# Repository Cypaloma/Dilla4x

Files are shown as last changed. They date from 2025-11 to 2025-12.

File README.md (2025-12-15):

# 🎛️ Dilla4x - Open Source Device Platform

**A minimalist, accessible 4x4 ortholinear input device inspired by classic MPC layouts.**

> *"Get ready for the up-and-coming, whatever it is." - J Dilla*

   

> 💭 **Stressed out? Overwhelmed?** Try the [Bio-Debugger](tools/bio-debugger/README.md) - a mental health resource for de-escalation during technical challenges.

---

## 🎵 What is Dilla4x?

The **Dilla4x** is a fully open-source hardware and software platform. Built around the **Arduino Pro Micro (ATmega32U4)**, it serves as both a serious creative tool and a learning platform for hardware development.

### ✨ Key Features

| Feature | Description |
| :--- | :--- |
| **🎹 16 Mechanical Keys** | Uses standard **Cherry MX-compatible** keyswitches for a responsive, premium feel. |
| **♿ Accessible Design** | Unique **"chord trigger" octave shifting** (MIDI firmware) or custom layouts via VIA allow full creative control for users with diverse needs. |
| **🔌 Plug-and-Play** | **USB HID/MIDI compatible**. Works instantly with DAWs, browsers, games, and creative software. No drivers needed. |
| **🛠️ Hackable Core** | Powered by **ATmega32U4**. Choose between MIDI or QMK firmware, or create your own. |
| **🔓 Open Hardware** | Simple PCB and 3D-printed enclosure designs that are easy to print, assemble, and modify. |

---

## 🚀 Quick Start

Everything you need to get started is in our comprehensive **[Wiki](wiki/Home.md)**.

1.  **🛠️ Build It**
    *   Follow the **[Step-by-Step Assembly Guide](wiki/hardware/Assembly-Guide.md)** to put your hardware together.
2.  **⚡ Flash Firmware**
    *   **Download from [GitHub Releases](https://github.com/Cypaloma/Dilla4x/releases/tag/v0.3.1)**:
        *   **MIDI Firmware** (v0.3.0): `dilla4x-midi-v0.3.0.hex` ✅ Stable
        *   **QMK Firmware** (v0.1.1-alpha): ⚠️ **ALPHA - UNTESTED ON HARDWARE**
            
            > **CAUTION**: This firmware has NOT been tested on physical hardware. All devices were sent to participants before testing. Use at your own risk and please report issues.
            
            1.  **Manual Reset Required**: Double-tap the physical reset button to enter bootloader mode. The auto-flash recovery script will **NOT** work for QMK.
            2.  Flash using QMK Toolbox or CLI:
                ```bash
                qmk flash dilla4x-qmk-v0.1.1-alpha.hex
                ```
3.  **🎧 Use It**
    *   **MIDI Mode**: Learn the layout in **[How to Use Dilla4x-MIDI](wiki/software/How-to-Use-Dilla4x-MIDI.md)**
    *   **QMK Mode**: Remap keys with VIA - see **[QMK README](firmware/qmk/dilla4x/readme.md)**
    *   **Web App**: Download `dilla4x-web-v0.1.0.zip` or use the **[Web Manual](wiki/software/Web-Dilla4x-Manual.md)**

---

## 🎹 Web Dilla4x Companion App

**No software to install.** The Dilla4x comes with a powerful browser-based companion app that turns your controller into a basic **Sampler and Synthesizer** instantly.

*   **Launch it**: Open [`tools/web-dilla4x/index.html`](tools/web-dilla4x/index.html) in Chrome/Edge
*   **Features**:
    *   **Sampler**: Drag & drop WAV/MP3s, per-pad pitch/envelope controls.
    *   **Synth**: Full subtractive synth engine with A/D envelope and low-pass filter.
    *   **Visualizer**: Real-time oscilloscope and VU meter.
*   **Manual**: [Read the Web Dilla4x Guide](wiki/software/Web-Dilla4x-Manual.md)

---

## 🧠 Firmware Options

The Dilla4x supports **two firmware modes** - choose based on your use case:

### 🎵 Dilla4x-MIDI Firmware (v0.3.0)

A stateless, low-latency MIDI engine designed for musical performance.

*   **💻 Source**: [`firmware/Dilla4x-MIDI/`](firmware/Dilla4x-MIDI/)
*   **✨ Features**:
    *   Chromatic MIDI notes (C2-D#3)
    *   Chord-based octave shifting (accessibility feature)
    *   Class-compliant USB MIDI
    *   Recovery mode for failed uploads
*   **📖 Guide**: [Firmware Documentation](wiki/development/Dilla4x_Firmware.md) | [Usage Manual](wiki/software/How-to-Use-Dilla4x-MIDI.md)
*   **🔧 Modify**: [Arduino IDE Guide](wiki/development/Arduino-Development.md) | [PlatformIO Guide](wiki/development/VSCodium-PlatformIO-MIDI-Guide.md)

### ⌨️ Dilla4x-QMK Firmware (v0.1.0)

A versatile QMK-based firmware for programmable macros, gaming, and accessibility.

*   **� Source**: [`firmware/qmk/dilla4x/`](firmware/qmk/dilla4x/)
*   **✨ Features**:
    *   VIA support for real-time remapping
    *   N-Key Rollover (NKRO)
    *   Mouse keys and media control
    *   MIDI mode support
    *   Community layout compatible (ortho_4x4)
*   **📖 Guide**: [QMK README](firmware/qmk/dilla4x/readme.md) | [VIA Setup](firmware/qmk/dilla4x/keymaps/via/VIA_SETUP.md)
*   **🔧 Modify**: Standard QMK development workflow

---

## 🔮 Roadmap

We are interested in expanding the Dilla4x ecosystem. Check [ROADMAP.md](ROADMAP.md) for full details.

Future directions:
- [ ] **Visual Arts**: Workflows for TouchDesigner, Resolume, and p5.js.
- [ ] **Ergonomics**: Low-profile enclosure designs.
- [ ] **Firmware Variants**: Additional community-contributed firmware options.

---

## 📂 Repository Structure

```text
├── 3d-prints/         # STL files for the enclosure
├── firmware/
│   ├── Dilla4x-MIDI/  # Arduino MIDI firmware (v0.3.0)
│   └── qmk/dilla4x/   # QMK programmable firmware (v0.1.0)
├── tools/
│   └── web-dilla4x/   # Browser-based sampler/synth app
├── wiki/              # Complete documentation (Build, Code, Play)
│   ├── development/   # Coding guides
│   ├── hardware/      # BOM & Assembly
│   ├── software/      # Usage manuals for both firmwares
│   └── sound/         # Music theory & creative guides
├── ROADMAP.md         # Future development plans
└── LICENSE            # Apache 2.0
```

---

## 🤝 Contributing

This project is open source under the **Apache 2.0 License**. Contributions to hardware, firmware, and documentation are welcome!

1.  Fork the repository
2.  Create your feature branch
3.  Submit a Pull Request

Whether you're interested in MIDI, QMK, hardware design, or creative applications - there's room for you to contribute!

---

*Dedicated to the legacy of James Dewitt Yancey.*

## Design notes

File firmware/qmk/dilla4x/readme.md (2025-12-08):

# Dilla4x

A 4x4 ortholinear MIDI controller and macro pad with VIA support.

* Keyboard Maintainer: [Dilla4x Community](https://github.com/Cypaloma/Dilla4x)
* Hardware Supported: ATmega32U4 (Arduino Pro Micro)
* Hardware Availability: [Build Guide](../../wiki/hardware/Assembly-Guide.md)

> **⚠️ TESTING STATUS**: This firmware (v0.1.0) follows 2025 QMK standards (data-driven config). It should compile correctly but has not been tested on hardware yet.

> **⚡ FIRMWARE SIZE**: ATmega32U4 has limited flash (28KB). VIA + MIDI + NKRO uses ~26KB. If you encounter size errors, disable NKRO or mousekeys in VIA keymap.

## Features

- **Dual Purpose**: MIDI controller + programmable macro pad
- **VIA Support**: Real-time remapping (requires external VIA definition - see below)
- **Gaming Ready**: N-Key Rollover, mouse keys, media control
- **MIDI Notes**: Chromatic C2-D#3 (matches Dilla4x-MIDI firmware)

## Make Commands

Compile default keymap:

    make dilla4x:default

Compile VIA keymap:

    make dilla4x:via

Flash to device (enter bootloader first):

    make dilla4x:via:flash

## Bootloader

Enter the bootloader in 3 ways:

* **Bootmagic reset**: Hold top-left key while plugging in
* **Physical reset**: Bridge RST to GND on Pro Micro twice quickly  
* **Keycode in layout**: Not implemented by default

## Default Keymap

Layer 0 - MIDI Notes (Chromatic C2 to D#3):

```
┌─────┬─────┬─────┬─────┐
│ C3  │ C#3 │ D3  │ D#3 │  MIDI 48-51
├─────┼─────┼─────┼─────┤
│ G#2 │ A2  │ A#2 │ B2  │  MIDI 44-47
├─────┼─────┼─────┼─────┤
│ E2  │ F2  │ F#2 │ G2  │  MIDI 40-43
├─────┼─────┼─────┼─────┤
│ C2  │ C#2 │ D2  │ D#2 │  MIDI 36-39
└─────┴─────┴─────┴─────┘
```

## VIA Support

**IMPORTANT**: VIA configuration is NOT stored in QMK firmware. You must:

1. Flash the `via` keymap to your device
2. Submit keyboard definition to [the-via/keyboards](https://github.com/the-via/keyboards)
3. Wait for PR approval

See [VIA_SETUP.md](keymaps/via/VIA_SETUP.md) for detailed instructions.

**Quick test** (before PR approval):
- Visit https://usevia.app/
- Go to "Design" tab
- Upload JSON from VIA_SETUP.md
- Test your layout

## Building from Source

### Prerequisites

Install QMK:

```bash
# macOS
brew install qmk/qmk/qmk

# Linux
python3 -m pip install --user qmk

# Windows - install QMK Toolbox
```

Setup QMK:

```bash
qmk setup
```

### Clone & Link

```bash
# Clone Dilla4x repo
git clone https://github.com/Cypaloma/Dilla4x.git
cd Dilla4x

# Link to QMK keyboards directory
ln -s "$(pwd)/firmware/qmk/dilla4x" ~/qmk_firmware/keyboards/dilla4x
```

### Compile

```bash
qmk compile -kb dilla4x -km via
```

### Flash

```bash
# Put device in bootloader mode, then:
qmk flash -kb dilla4x -km via
```

## Firmware Details

- **MCU**: ATmega32U4
- **Bootloader**: Caterina
- **Layout**: 4x4 ortholinear (16 keys direct pin)
- **MIDI**: Basic mode (Note On/Off, fixed velocity)
- **Debounce**: 30ms (matches Arduino firmware)

## Resources

* [QMK Documentation](https://docs.qmk.fm/)
* [VIA Configurator](https://usevia.app/)
* [Build Guide](../../wiki/hardware/Assembly-Guide.md)
* [Arduino Firmware](../Dilla4x-MIDI/)

## License

Apache 2.0 (same as parent project)

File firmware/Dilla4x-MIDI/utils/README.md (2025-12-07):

# Dilla4x Diagnostic Utilities

Central hub for hardware diagnostics and firmware testing tools.

## Quick Decision Tree

**What are you doing?**

1. **Just finished soldering Arduino to headers (bottom section only)**
   - Use: [`crosstalk_detector`](#crosstalk_detector)
   - Purpose: Check for solder bridges between pins

2. **Assembled full unit (buttons attached to Arduino)**
   - Use: [`connection_scout`](#connection_scout)
   - Purpose: Verify button connections and pin mapping

3. **Device won't flash / USB not responding**
   - Use: [`recovery`](#recovery)
   - Purpose: Unbrick device with minimal firmware

4. **Debugging firmware logic (debounce, MIDI, etc.)**
   - Use: [`testing/firmware_test`](#firmware-test)
   - Purpose: Test firmware with configurable modes

---

## Production Testing Workflow

```
┌─────────────────────────────────────────┐
│ 1. Bottom Section QA                    │
│    ├─ Solder Arduino Pro Micro to headers│
│    └─ Run: crosstalk_detector           │
│       ✓ Clean = No shorts detected      │
│       ✗ Issue = Fix solder bridges      │
└─────────────────────────────────────────┘
                   ↓
┌─────────────────────────────────────────┐
│ 2. Full Assembly QA                     │
│    ├─ Attach top button section          │
│    └─ Run: connection_scout              │
│       ✓ Clean = All buttons respond     │
│       ✗ Issue = Check button wiring     │
└─────────────────────────────────────────┘
                   ↓
┌─────────────────────────────────────────┐
│ 3. Functional Test                      │
│    └─ Flash main firmware                │
│       ✓ Pass = Device ready for use     │
│       ✗ Bricked = Use recovery tool     │
└─────────────────────────────────────────┘
```

---

## Utility Reference

### `crosstalk_detector`
**Tests**: Bottom section (Arduino + headers)  
**Detects**: Solder bridges between pins

**When to use**:
- After soldering Arduino Pro Micro
- Before attaching buttons
- When ghost presses occur (multiple keys at once)

**Expected output**:
- ✅ **Clean**: `Status: Clean (No Crosstalk Detected)`
- ❌ **Issue**: `SHORT DETECTED: Pin X <---> Pin Y`

**Location**: [`utils/crosstalk_detector/`](file:///home/morp/Documents/coding/projects/Dilla4x/firmware/Dilla4x-MIDI/utils/crosstalk_detector/)

---

### `connection_scout`
**Tests**: Top section (button connections)  
**Detects**: Button-to-pin mappings and connection integrity

**When to use**:
- After full assembly
- When a button doesn't respond
- To verify Config.h pin mapping

**Expected output**:
- ✅ **Clean**: Only shows activity when buttons pressed
- ❌ **Issue**: Pins stuck LOW or no response

**Location**: [`utils/connection_scout/`](file:///home/morp/Documents/coding/projects/Dilla4x/firmware/Dilla4x-MIDI/utils/connection_scout/)

---

### `recovery`
**Purpose**: Unbrick device when main firmware crashes  
**Includes**: Auto-flash script for automated recovery

**When to use**:
- Device won't show up in Arduino IDE
- USB enumeration fails
- Main firmware locks up device

**How to use**:
1. Flash `recovery.ino` to device
2. If upload fails, run `./auto_flash.sh`
3. Device will blink TX LED (confirmed recovery mode)
4. Flash desired firmware

> [!NOTE]
> **Recovery vs Firmware Recovery Mode**  
> - **This tool** (`recovery/`): Separate minimal sketch for unbricking
> - **Firmware recovery mode**: Hold Keys 0+15 at boot (built into main firmware)

> [!IMPORTANT]
> **Sometimes recovery firmware must be flashed first** if the current firmware utilizes the USB interface, preventing normal uploads.

**Location**: [`utils/recovery/`](file:///home/morp/Documents/coding/projects/Dilla4x/firmware/Dilla4x-MIDI/utils/recovery/)

---

### `firmware_test`
**Purpose**: Configurable test harness for debugging firmware  
**Located in**: [`testing/firmware_test/`](file:///home/morp/Documents/coding/projects/Dilla4x/firmware/Dilla4x-MIDI/testing/firmware_test/)

**Test modes** (configure in source):
- `TEST_WATCHDOG`: Enable/disable watchdog timer
- `TEST_MIDIUSB`: Enable/disable MIDIUSB library (tests pin conflicts)
- `TEST_VERBOSE`: Detailed trace logging

**When to use**:
- Debugging debounce logic
- Testing if MIDIUSB causes issues
- Validating firmware changes

**See**: [`testing/README.md`](file:///home/morp/Documents/coding/projects/Dilla4x/firmware/Dilla4x-MIDI/testing/README.md) for full testing documentation

---

## Manual Reset Button Access

> [!WARNING]
> **Current limitation**: Reset button requires disassembly to access (must jump reset pin to ground with screwdriver).
> 
> **Future improvement** (see [ROADMAP.md](file:///home/morp/Documents/coding/projects/Dilla4x/ROADMAP.md)):  
> Add small hole in bottom plate for tac switch, allowing reset access with assembly screwdriver.

---

## Troubleshooting

### "Device not detected by Arduino IDE"
1. Check USB cable (must be data cable, not charge-only)
2. Try [`recovery`](#recovery) tool with auto-flash script
3. Manually jump reset to ground twice quickly (bootloader mode)

### "Multiple buttons trigger at once"
- Run [`crosstalk_detector`](#crosstalk_detector) on bottom section
- Look for solder bridges between pins

### "One button doesn't work"
- Run [`connection_scout`](#connection_scout)
- Check if pin shows activity when button pressed
- Verify pin matches Config.h mapping

### "Firmware behaves strangely"
- Use [`firmware_test`](#firmware-test) to isolate issue
- Test with MIDIUSB disabled, watchdog disabled, etc.

---

## Contributing

When adding new utilities:
1. Create subdirectory in `utils/`
2. Add standardized header comment (see existing utilities)
3. Create `README.md` in utility directory
4. Update this central README with decision tree entry

**See**: [ROADMAP.md](file:///home/morp/Documents/coding/projects/Dilla4x/ROADMAP.md) for planned improvements

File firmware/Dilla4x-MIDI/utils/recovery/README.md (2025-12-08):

# Recovery Tool

Minimal firmware for unbricking soft-locked devices.

## Purpose

Provides a **safe idle state** when main firmware crashes or prevents USB upload.

## When to Use

- ❌ Device won't show up in Arduino IDE
- ❌ USB enumeration fails  
- ❌ Main firmware locks up device
- ❌ Normal upload fails with timeout errors

> [!IMPORTANT]
> **Two Different Recovery Mechanisms**:
> 
> 1. **This tool** (`recovery/`): Separate minimal sketch for complete unbrick
> 2. **Firmware recovery mode**: Built into main firmware (hold Keys 0+15 at boot)
> 
> Use **this tool** if firmware recovery mode doesn't work or main firmware won't let you upload.

> [!NOTE]
> **Sometimes recovery firmware must be flashed first** if current firmware utilizes USB interface, preventing normal uploads.

## Tools Included

- **`recovery.ino`**: Minimal blink sketch (TX LED only)
- **`auto_flash.sh`**: Linux automated upload script
- **`auto_flash.bat`**: Windows automated upload script
- **`auto_flash_mac.command`**: macOS automated upload script (double-clickable in Finder)

## Usage

### Linux
```bash
cd firmware/Dilla4x-MIDI/utils/recovery/
./auto_flash.sh
```

### Windows
1. Open Command Prompt or PowerShell
2. Navigate to `firmware\Dilla4x-MIDI\utils\recovery\`
3. Run `auto_flash.bat`
```cmd
cd firmware\Dilla4x-MIDI\utils\recovery
auto_flash.bat
```

### macOS
**Option A (Finder)**: Double-click `auto_flash_mac.command`  
**Option B (Terminal)**:
```bash
cd firmware/Dilla4x-MIDI/utils/recovery/
./auto_flash_mac.command
```

> [!NOTE]
> All scripts require `arduino-cli` to be installed and in your PATH.
> Install from https://arduino.github.io/arduino-cli/

### Method 1: Manual Upload

```bash
cd firmware/Dilla4x-MIDI/utils/recovery/

# Try normal upload first
arduino-cli upload -p /dev/ttyACM0 --fqbn arduino:avr:micro ./

# If that fails, manually jump reset to ground twice (bootloader mode)
# Then immediately upload
arduino-cli upload -p /dev/ttyACM0 --fqbn arduino:avr:micro ./
```

### Method 2: Automated (Recommended)
```bash
cd firmware/Dilla4x-MIDI/utils/recovery/

# Run auto-flash script (watches for ports, handles bootloader)
./auto_flash.sh

# Optional: Specify specific port
PORT_HINT=/dev/ttyACM0 ./auto_flash.sh
```

## What It Does

1. Compiles `recovery.ino` to hex
2. Watches for USB serial ports
3. Attempts upload with retries
4. Periodically triggers bootloader with 1200bps touch
5. Continues until upload succeeds

## Expected Behavior

### After Successful Upload
- **TX LED blinks** rapidly (150ms on/off)
- **RX LED stays off**
- Device appears as `/dev/ttyACM*` in Arduino IDE
- Normal firmware can now be uploaded

### If Still Failing
1. Check USB cable (must be data cable, not charge-only)
2. Try different USB port on computer
3. Verify Arduino Pro Micro isn't damaged (check for shorts/burns)
4. Try manual bootloader trigger (double-tap reset)

## Auto-Flash Script Details

**Environment variables**:
- `FQBN`: Board type (default: `arduino:avr:micro`)
- `PORT_HINT`: Specific port to target (optional)
- `BUILD_DIR`: Custom build directory (optional)

**How it works**:
- Continuously scans for ports
- Attempts rapid uploads when port detected
- Sends 1200bps reset signal to trigger bootloader
- Retries until successful

## Troubleshooting

### "No ports found"
- Device not connected or completely bricked  
- Check for power LED on Arduino
- Try different computer/USB port

### "Upload fails immediately"
- Bootloader might be corrupted  
- Need ISP programmer to reflash bootloader

### "Device reappears but still can't upload main firmware"
- Recovery is working, but main firmware has USB conflict
- Flash recovery again, then immediately upload main firmware

## Next Steps

After successful recovery:
1. Device should blink TX LED
2. Open Arduino IDE
3. Upload desired firmware
4. Test functionality with [`connection_scout`](../connection_scout/)

---

[← Back to Utils](../README.md)

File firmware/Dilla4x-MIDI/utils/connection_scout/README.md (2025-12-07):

# Connection Scout

Scans all digital pins to identify active button connections and verify wiring.

## Purpose

Tests **TOP SECTION** (buttons) after bottom section passes crosstalk detection.

## When to Use

- ✅ After assembling full device (buttons attached to Arduino)
- ✅ Debugging "button not responding" issues  
- ✅ Verifying pin mapping matches Config.h
- ✅ Production QA of assembled units

## How It Works

1. Configures all pins (2-21) as INPUT_PULLUP
2. Continuously scans for LOW signals (pressed buttons)
3. Reports active pins with Config.h validation
4. Shows periodic scan summary

## Expected Output

### Clean Operation
```
=== DILLA4X CONNECTION SCOUT ===
Scanning pins 2-21
Press buttons to identify pin assignments

ACTIVITY DETECTED ON PIN: 2 ✓ [Expected Key Pin]
ACTIVITY DETECTED ON PIN: 5 ✓ [Expected Key Pin]
SCAN: (All pins HIGH - No buttons pressed)
```

### Issue: Unexpected Pin
```
ACTIVITY DETECTED ON PIN: 13 ⚠ [NOT in Config.h - Check wiring]
```
**Action**: Verify wiring - this pin shouldn't have a button

### Issue: Pin Stuck LOW
```
SCAN: [PIN 7:0!] [PIN 7:0!] [PIN 7:0!] 
```
**Action**: Pin 7 shorted to ground or button stuck - check soldering/button

## Usage

```bash
# Navigate to utility
cd firmware/Dilla4x-MIDI/utils/connection_scout/

# Upload to device (replace port as needed)
arduino-cli upload -p /dev/ttyACM0 --fqbn arduino:avr:micro ./

# Open serial monitor
arduino-cli monitor -p /dev/ttyACM0
```

## Visual Indicators

- **TX LED blinks** every 500ms (heartbeat - device is alive)
- **Serial output** shows button activity in real-time

## Config.h Pin Reference

Expected button pins:
```
Row 0: 2, 3, 4, 5
Row 1: 6, 7, 8, 9
Row 2: 10, 16, 14, 15
Row 3: A0(18), A1(19), A2(20), A3(21)
```

## Related Tools

- **Before this**: Run [`crosstalk_detector`](../crosstalk_detector/) on bottom section
- **After this**: Flash main firmware for functional testing
- **If bricked**: Use [`recovery`](../recovery/) tool

---

[← Back to Utils](../README.md)

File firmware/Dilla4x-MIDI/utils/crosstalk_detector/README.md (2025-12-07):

# Crosstalk Detector

Systematically detects physical shorts (solder bridges) between pins.

## Purpose

Tests **BOTTOM SECTION** (Arduino + headers) for crosstalk before attaching buttons.

## When to Use

- ✅ After soldering Arduino Pro Micro to headers
- ✅ **Before** attaching top button section
- ✅ When multiple buttons trigger simultaneously (ghost presses)
- ✅ Production QA of bottom assemblies

## How It Works

1. Sets all pins to INPUT_PULLUP (safe state)
2. Drives each pin LOW one at a time
3. Checks if any other pins get pulled LOW
4. Reports physical shorts between pins

## Expected Output

### Clean Board
```
=== DILLA4X CROSSTALK DETECTOR ===
Starting Short Circuit Scan...
--- Scanning ---
Status: Clean (No Crosstalk Detected)
```

### Solder Bridge Detected
```
--- Scanning ---
SHORT DETECTED: Pin 3 (Key 1) <---> Pin 4 (Key 2)
SHORT DETECTED: Pin 8 (Key 7) <---> Pin 9 (Key 8)
```

**Action**: Inspect solder joints between reported pins - likely solder bridge or whisker

## Usage

```bash
# Navigate to utility
cd firmware/Dilla4x-MIDI/utils/crosstalk_detector/

# Upload to device
arduino-cli upload -p /dev/ttyACM0 --fqbn arduino:avr:micro ./

# Open serial monitor
arduino-cli monitor -p /dev/ttyACM0
```

## What It Tests

- ✅ All 16 key pins from Config.h
- ✅ Pins: 2,3,4,5,6,7,8,9,10,16,14,15,A0,A1,A2,A3

## Interpreting Results

| Output | Meaning | Action |
|---|---|---|
| `Status: Clean` | No shorts detected | ✅ Proceed to button assembly |
| `SHORT DETECTED` | Physical bridge between pins | ❌ Fix solder joint, retest |

## Common Causes of Shorts

1. **Solder bridges**: Excess solder connecting adjacent header pins
2. **Whiskers**: Thin solder strands bridging pins
3. **Flux residue**: Conductive flux (rare with modern flux)

## Testing Frequency

- **Always** after soldering headers
- **Always** after rework/repair
- **Once** per production unit (QA)

## Related Tools

- **After this**: Run [`connection_scout`](../connection_scout/) on full assembly
- **Before this**: Visual inspection of solder joints

---

[← Back to Utils](../README.md)

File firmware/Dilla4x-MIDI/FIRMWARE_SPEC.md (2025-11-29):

# Dilla4x Firmware Specification (v0.3)

## 1. Design Philosophy
- **Simplicity**: The codebase prioritizes readability and maintainability. Complex algorithms are avoided.
- **Statelessness**: The device is explicitly designed to be stateless. It resets to a known good state (Octave 0) on every power cycle. This eliminates flash wear, EEPROM corruption risks, and the need for complex factory reset procedures.
- **Robustness**: The device must never enter a state that requires external hardware to fix. "Unbrickability" is a core requirement.
- **Predictability**: State changes occur only on explicit, debounced user actions.

## 2. Hardware Abstraction
### 2.1 Pin Mapping
The firmware targets the **Arduino Pro Micro / Leonardo (ATmega32U4)**.
- **Keys**: 16 keys arranged in a 4x4 physical grid but wired directly to digital pins.
    - **Row 0**: Pins 2, 3, 4, 5
    - **Row 1**: Pins 6, 7, 8, 9
    - **Row 2**: Pins 10, 16, 14, 15
    - **Row 3**: Pins A0, A1, A2, A3
- **LED**: Built-in LED on `LED_BUILTIN` (Pin 13).

### 2.2 Input Handling
- **Method**: Direct `digitalRead` in a loop.
- **Debouncing**: Handled by `Control_Surface` library for notes, and custom state machine for Chords.

## 3. Functional Logic

### 3.1 MIDI Note Generation
- **Library**: `Control_Surface` handles USB MIDI.
- **Mapping**: Each key maps to a specific MIDI note on Channel 1.
- **Transposition**: Global `Transposer` modifies output based on Octave.

### 3.2 Octave Shifting (Chord System)
- **Trigger**: All 8 keys on one side held for >300ms.
    - **Octave Down**: Left half (Cols 0-1) - all 8 keys.
    - **Octave Up**: Right half (Cols 2-3) - all 8 keys.
- **Threshold**: All 8 keys required (no partial chord support).
- **Range**: -3 to +3 octaves.
- **State Machine**:
    1.  **IDLE**: Monitoring.
    2.  **DEBOUNCING**: Valid mask detected.
    3.  **TRIGGERED**: Held for ≥300ms. Action fires once.
- **Safety**: Sends Note Off for all keys before shifting.

### 3.3 LED Feedback
- **Recovery Mode**: Fast continuous blinking (100ms).
- **Feedback Blink**: Short blink (50ms) on Octave Shift.
- **Key Press**: Solid ON.
- **Idle**: OFF.
- **Responsiveness**: Feedback timeout is set to **300ms** to ensure the LED is ready for subsequent inputs during rapid octave shifting.

### 3.4 Recovery Mode
- **Purpose**: Fail-safe to restore device if main app crashes.
- **Trigger**: Holding **Key 0 (Pin 2)** and **Key 15 (Pin A3)** during power-up.
- **Behavior**: Enters infinite loop with LED blinking. Exposes USB CDC for Arduino IDE to trigger bootloader.
- **Note**: This is distinct from a "Factory Reset" (which is not needed as there is no persistent state).

## 4. Data Persistence
- **None**: The device does not use EEPROM.
- **Rationale**:
    - **Longevity**: Eliminates EEPROM write cycles, ensuring the flash memory never wears out.
    - **Simplicity**: Removes complex code for wear leveling, CRC validation, and atomic writes.
    - **Reliability**: A power cycle is guaranteed to fix any logical state issue (except firmware corruption, handled by Recovery Mode).

## 5. Watchdog
- **Enabled**: Watchdog timer is enabled with a 4-second timeout to reset the device in case of a hang.

## 6. Out of Scope (DO NOT OVER-ENGINEER)

The following scenarios are explicitly **out of scope** and require NO firmware handling:

### 6.1 USB Disconnection
- **Reality**: USB disconnection removes power from the device. The device turns off.
- **Action**: None. The `Control_Surface` library handles USB stack. Firmware does not detect or respond to USB states.

### 6.2 "MIDI Failures"
- **Reality**: The `Control_Surface` library abstracts the USB MIDI stack and handles all protocol details.
- **Action**: None. If MIDI doesn't work, it's a library issue or host driver issue, not a firmware concern.

### 6.3 Hardware Faults
- **Reality**: If a key physically breaks, a solder joint fails, or the PCB is damaged, no amount of firmware can fix it.
- **Action**: None. Hardware faults require physical repair.

### 6.4 Memory/Stack Corruption
- **Reality**: If memory corruption occurs, the watchdog will reset the device. If the watchdog itself is corrupted, the device is already non-functional.
- **Action**: None beyond the existing watchdog timer. Do not add redundant checks.

### 6.5 External Error Recovery
- **Reality**: This is a simple USB MIDI controller, not a safety-critical system.
- **Action**: If the device is in a bad state, the user can unplug it. That is sufficient.

## 7. Directory Structure
- `Config.h`: Constants and pin definitions.
- `Utils.h/cpp`: Hardware helpers.
- `ChordManager.h/cpp`: Chord logic.
- `LedController.h/cpp`: LED logic.
- `Dilla4x.ino`: Main entry point.
- **Deleted**: `StateManager.h/cpp` (Removed in v0.3).

---

## 8. Common Misconceptions (For Code Reviewers)

This section addresses common false critiques that arise from misunderstanding embedded development:

### 8.1 "Missing pinMode Configuration"
**FALSE**. The Control_Surface library automatically configures pinMode for all NoteButton pins when `Control_Surface.begin()` is called. Explicit pinMode() calls are NOT needed and would be redundant. See lines 22-39 and line 127 in Dilla4x.ino.

### 8.2 "Watchdog Kills Recovery Mode"
**FALSE**. The watchdog is enabled at line 128 AFTER the recovery mode check at line 123. If recovery mode is active, `enterRecoveryMode()` never returns (it's an infinite loop), so the watchdog enable code is never reached. There is no watchdog reset issue.

### 8.3 "Recovery Mode Should Have Timeout"
**FALSE - THIS IS BY DESIGN**. Recovery mode is an infinite loop with NO timeout by design. It provides a "safe idle state" for firmware upload when the device is soft-bricked. The only exits are power cycle or successful firmware upload. This is intentional, not a bug.

### 8.4 "timeElapsed() is Unnecessarily Complex"
**FALSE**. Simple comparison `(currentTime >= targetTime)` FAILS with wraparound. If target=100 and current wraps to 5, then `5 >= 100` is FALSE (wrong!). The `(a - b) < ULONG_MAX/2` pattern is the CORRECT and STANDARD way to handle unsigned time wraparound in embedded systems. See Utils.h for detailed explanation.

### 8.5 "LED Feedback Has Race Condition"
**FALSE**. Setting `g_feedbackEndTime = millis() + timeout` is safe even near ULONG_MAX because unsigned arithmetic wraps correctly and `timeElapsed()` uses the wraparound-safe comparison pattern. This is not a race condition.

### 8.6 "No MIDI Validation"
**FALSE**. The Control_Surface library handles all MIDI initialization and validation. If `Control_Surface.begin()` fails, it's a library bug, not a firmware issue. We don't need additional validation.

### 8.7 "Port Optimization is Premature"
**FALSE**. Direct port access is STANDARD PRACTICE in professional embedded systems. For 16 pins read every loop iteration, this matters for responsiveness. The lookup tables are computed at compile time (zero runtime cost). This is how production Arduino MIDI controllers are written.

### 8.8 "Ambiguous Chord Detection Creates Undefined Behavior"
**FALSE**. When both chords are pressed simultaneously (line 16-18 in ChordManager.cpp), returning NONE without state change is correct behavior. The state machine remains in its current state, which is well-defined. When the ambiguity resolves, normal state transitions resume.

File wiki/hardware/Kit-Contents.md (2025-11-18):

# Dilla4x Kit Contents

## Complete Package Overview

### Core Components
- **Enclosure System**:
  - Top Plate: Precision-milled ABS for Cherry MX keyswitches
  - Bottom Plate: Reinforced PETG with component mounting points
  - 16x M3 Screws & Brass Threaded Inserts (pre-installed)

- **Input System**:
  - 16x Cherry MX Mechanical Keyswitches (Linear Red)
  - 16x Custom Keycaps (Dye-sublimated PBT)
  - Silicone dampeners for silent operation

### Electronics Package
- **Control Board**:
  - Arduino Pro Micro (ATmega32U4 @ 16MHz)
  - 74HC4051 8-Channel Analog Multiplexer
  
- **Connectivity**:
  - USB-C Cable (1.8m braided nylon)
  - 40x Dupont Jumper Wires (M-M, 20cm)
  - Solderless Breadboard (400 tie-points)

### Tools & Accessories
- Included Tools:
  - Precision Screwdriver (PH1/PZ0)
  - Spare M3 Screws (Stainless Steel)

- Recommended Tools:
  - Hot Glue Gun (Low-Temp)
  - Flush Cutters (for wire trimming)
  - Digital Multimeter

## Technical Specifications

### Pin Assignments
- **Digital Inputs** (K1-K12):
  ```
  2, 3, 4, 5, 6, 7, 8, 9, 10, 11, 12, 13
  ```
- **Analog Inputs** (K13-K16):
  ```
  A0, A1, A2, A3
  ```

### Electrical Specifications
- Operating Voltage: 5V DC
- Current Draw: 100mA (idle), 500mA (max)
- USB Compliance: USB 2.0 Full Speed
- Debounce: 100ms hardware filtering

## Starting Assembly
1. **Component Verification**: Cross-check with this list
2. **Workspace Preparation**: Clean, well-lit area
3. **Firmware Ready**: Download from [Dilla4x Releases](https://github.com/yourrepo/releases)
4. **Driver Setup**: Install Arduino Leonardo drivers

👉 Proceed to [Step-by-Step Assembly Guide](Assembly-Guide.md)

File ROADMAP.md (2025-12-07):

# Dilla4x Development Roadmap

Future improvements and planned development for the Dilla4x MIDI controller.

---

## Priority 1: Hardware Improvements

### Reset Button Access Hole
**Status**: 🔴 Not Started  
**Priority**: High  
**Effort**: Low (hardware only)

**Problem**:
Currently, accessing the reset pin to short it and load another sketch to the Arduino requires full disassembly. To enter bootloader mode or trigger recovery, users must:
1. Remove screws
2. Separate top and bottom sections
3. Jump reset pin to ground with screwdriver
4. Reassemble

This is cumbersome for development and production QA.

**Proposed Solution**:
Add a small hole in the bottom plate of the enclosure for a tac switch:
- **Location**: Aligned with Arduino Pro Micro reset button
- **Switch**: Small tac switch glued to bottom plate interior
- **Access**: Accessible with same screwdriver used for assembly screws
- **Benefit**: Reset without disassembly

**Implementation Steps**:
1. Measure Arduino Pro Micro reset button position
2. Add hole to bottom plate 3D model (CAD)
3. Test fit with tac switch
4. Update assembly documentation
5. Validate in production units

**Impact**:
- ✅ Easier bootloader access
- ✅ Faster recovery mode entry
- ✅ Simplified development workflow
- ✅ Better production QA process

---

## Priority 2: Testing Infrastructure

### Unit Tests for Debounce Logic
**Status**: 🔴 Not Started  
**Priority**: Medium  
**Effort**: Medium

**Goal**: Automated unit tests for debounce state machine

**Approach**:
- Mock `millis()` and `digitalRead()`
- Test state transitions with controlled timing
- Validate edge cases (simultaneous presses, rapid bounces, etc.)
- Framework: ArduinoUnit or custom test harness

**Benefits**:
- Catch regressions before deployment
- Document expected behavior
- Enable confident refactoring

---

### Integration Tests for MIDI Output
**Status**: 🔴 Not Started  
**Priority**: Medium  
**Effort**: Medium

**Goal**: Validate MIDI output matches expected note events

**Approach**:
- Capture USB MIDI traffic programmatically
- Simulate button presses (GPIO manipulation or hardware fixture)
- Assert correct MIDI messages sent
- Test octave shifting, note-on/off, velocity

**Tools Required**:
- MIDI monitor library (e.g., `mido` in Python)
- GPIO control (mock or real hardware)
- Test fixture for repeatable button actuation|

---

### QMK Firmware Support
**Status**: 🔴 Not Started
**Priority**: Medium
**Effort**: High

**Goal**: Port QMK (Quantum Mechanical Keyboard) firmware to Dilla4x.

**Benefits**:
- Advanced keymapping (layers, tap-dance, macros)
- VIA/Vial support for real-time configuration
- Standard keyboard functionality (typing mode)

---

### Visual Art Integration
**Status**: 🔴 Not Started
**Priority**: Medium
**Effort**: Medium

**Goal**: workflows and guides for using Dilla4x with visual arts software.

**Use Cases**:
- Triggering video clips (VJing) in Resolume/VDMX
- Controlling generative graphics (TouchDesigner, Processing, p5.js)
- Interactive installation control

---

### Hardware Ergonomics: Height Reduction
**Status**: 🔴 Not Started
**Priority**: Low
**Effort**: High (Redesign)

**Problem**: The current enclosure is relatively tall, which can affect wrist comfort during long sessions.

**Goal**: Redesign the enclosure/PCB mounting to reduce overall height.
- Lower profile switches?

---

## Priority 3: Features & Enhancements

### Feature Requests
**Status**: 🟡 Collecting Ideas  
**Priority**: TBD

**Potential Features** (subject to user feedback):
- Velocity sensitivity (requires hardware change - FSR or pressure sensors)
- Configurable MIDI channel (stored in EEPROM - conflicts with stateless design)
- Alternate chord modes (different octave shift patterns)
- LED feedback customization/optimization
- USB MIDI + DIN MIDI dual output

**Evaluation Criteria**:
- Maintains design philosophy (simplicity, statelessness, robustness)
- No significant complexity increase
- User demand
- Backward compatibility

---

## How to Contribute

**Proposing Features**:
1. Open issue in repository
2. Describe use case and rationale
3. Consider impact on design philosophy
4. Wait for discussion/approval

**Implementing Roadmap Items**:
1. Choose item from roadmap
2. Create branch
3. Implement with tests
4. Update this roadmap
5. Submit pull request

---

## Notes

- **Hardware changes** require coordination with 3D print files
- **Testing infrastructure** builds on existing `testing/` directory
- All changes must maintain **zero EEPROM usage** (stateless design)
- See [`FIRMWARE_SPEC.md`](firmware/Dilla4x-MIDI/FIRMWARE_SPEC.md) for design constraints

---

**Last Updated**: 2025-12-07

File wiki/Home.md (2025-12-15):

# Dilla4x MIDI Controller Wiki

Welcome to the Dilla4x MIDI Controller documentation! This comprehensive guide covers everything from building to customizing your 4x4 MIDI controller.

## 🎵 What is Dilla4x?
The Dilla4x is a minimalist 4x4 ortholinear MIDI controller inspired by classic MPC layouts. It features:
- **16 Cherry MX keyswitches** in a 4x4 grid
- **Octave shift functionality** via chord triggers
- **Plug-and-play USB MIDI** compatibility
- **Open source** hardware and firmware
- **Accessible design** following anti-ableist principles

## 🚀 Quick Start Guide
1. 🧰 [Verify Kit Contents](hardware/Kit-Contents.md)
2. 🔧 [Assemble Hardware](hardware/Assembly-Guide.md)
3. 💻 [Setup Software](development/Arduino-Development.md)
4. 🎛️ [Upload Firmware](development/Dilla4x_Firmware.md)
5. 🎵 [Start Making Music](software/How-to-Use-Dilla4x-MIDI.md)

## 📚 Documentation

### Development
- [Arduino Setup](development/Arduino-Development.md)
- [VSCodium + PlatformIO (MIDI Firmware)](development/VSCodium-PlatformIO-MIDI-Guide.md)
- [Dilla4x MIDI Firmware Guide](development/Dilla4x_Firmware.md)

### Hardware
- [Complete Parts List](hardware/Kit-Contents.md)
- [Step-by-Step Assembly](hardware/Assembly-Guide.md)
- [Troubleshooting](../Troubleshooting.md)

### 🧠 Software & Manuals
- **[How to Use Dilla4x-MIDI](software/How-to-Use-Dilla4x-MIDI.md)** - Complete usage guide for the MIDI firmware (v0.3.0)
- **[How to Use Dilla4x-QMK](software/How-to-Use-Dilla4x-QMK.md)** - Complete usage guide for the QMK firmware (v0.1.1-alpha - UNTESTED)
- **[Web Dilla4x Manual](software/Web-Dilla4x-Manual.md)** - Browser-based sampler/synth companion app

### Sound & Music
- [Music Making Overview](sound/Music-Making-Overview.md)
- [Beginner's Guide](sound/Beginner-Guide.md)

### Mental Health & Accessibility
- **[Bio-Debugger](Bio-Debugger-Page-1.md)** - Access-first protocol for technical overwhelm (3-page guide)

## 🛠️ Technical Specifications
- **Microcontroller**: Arduino Pro Micro (ATmega32U4)
- **Connectivity**: USB-C
- **Keyswitches**: 16x Cherry MX compatible
- **MIDI Implementation**: USB MIDI via Control_Surface library
- **Dimensions**: Compact 3D-printed enclosure

## 🔧 Assembly Overview
The hardware build has three phases:
1. **Enclosure Assembly** - 3D printed case
2. **Electronics Installation** - Arduino & wiring
3. **Final Assembly** - Closing the housing

👉 [Full Assembly Guide](hardware/Assembly-Guide.md) (30-60 minutes)

## 💻 Software Setup
Choose your environment:
- **Beginner**: [Arduino IDE](development/Arduino-Development.md)
- **Advanced**: [VSCodium + PlatformIO](development/VSCodium-PlatformIO-MIDI-Guide.md)

## 🎧 Creative Uses
- Beat making and drum programming
- Melody and bassline creation
- Live performance control
- DAW integration
- Accessible music creation

## ⚙️ Customization
- Modify firmware key mappings
- Add LED feedback
- Create custom overlays
- Expand with additional hardware

## 👥 Community & Course
This project is part of a closed course that will be released as open source. All materials will be available for community contribution.

## 📖 Quick Reference
- **Octave Controls**:
  - Top 8 keys: +1 octave
  - Bottom 8 keys: -1 octave
  - Range: -2 to +2 octaves
- **Note Layout**: Chromatic from C1 (36) to C3 (51)

---
**Need Help?**
Check our [Troubleshooting Guide](Troubleshooting.md) or ask in the community forum!

**Contributors Welcome!**
This documentation will be available for open source community contributions.

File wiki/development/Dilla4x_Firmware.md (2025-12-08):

# Dilla4x MIDI Firmware (v0.3) Technical Documentation

Technical reference for the **Dilla4x Standard MIDI Firmware**.

> [!NOTE]
> **Scope**: This document covers the standalone MIDI firmware (`firmware/Dilla4x-MIDI`).
> Future firmwares (e.g., QMK) will be documented separately.
>
> **For user-facing instructions**, see [How to Use Your Dilla4x](../software/How-to-Use-Dilla4x-MIDI.md).  

> This document is for developers and technical users.

---

## Overview

The Dilla4x firmware implements a 16-key USB MIDI controller with chord-based octave shifting, optimized for low latency and accessibility.

**Key Specifications**:
- **Target Hardware**: Arduino Pro Micro (ATmega32U4 @ 16MHz, 5V)
- **MIDI Implementation**: Native MIDIUSB library (class-compliant USB MIDI)
- **Latency**: ~10ms total (debounce + USB polling)
- **Memory Footprint**: ~19KB flash, ~1.3KB SRAM
- **Design Philosophy**: Stateless, simple, robust

---

## Hardware Configuration

### Pin Assignments

16 keys mapped directly to digital pins with `INPUT_PULLUP`:

| Key | Position | Pin | Base Note | MIDI Note |
|-----|---|-----|---|---|
| K1  | Row1 Col1 | 2 | C3  | 48 |
| K2  | Row1 Col2 | 3 | C#3 | 49 |
| K3  | Row1 Col3 | 4 | D3  | 50 |
| K4  | Row1 Col4 | 5 | D#3 | 51 |
| K5  | Row2 Col1 | 6 | G#2 | 44 |
| K6  | Row2 Col2 | 7 | A2  | 45 |
| K7  | Row2 Col3 | 8 | A#2 | 46 |
| K8  | Row2 Col4 | 9 | B2  | 47 |
| K9  | Row3 Col1 | 10  | E2  | 40 |
| K10 | Row3 Col2 | 16  | F2  | 41 |
| K11 | Row3 Col3 | 14  | F#2 | 42 |
| K12 | Row3 Col4 | 15  | G2  | 43 |
| K13 | Row4 Col1 | A0  | C2  | 36 |
| K14 | Row4 Col2 | A1  | C#2 | 37 |
| K15 | Row4 Col3 | A2  | D2  | 38 |
| K16 | Row4 Col4 | A3  | D#2 | 39 |

**Note Layout**: Chromatic scale, ascending from bottom-left (C2) to top-right (D#3).

**Wiring**:
- Button contact 1 → Digital pin
- Button contact 2 → GND
- Internal pullup resistors enabled (`INPUT_PULLUP`)
- Active-LOW logic (button press = pin reads LOW)

### LED Feedback

Built-in TX LED (active-LOW on PORTD bit 5):
- **Solid ON**: Key(s) pressed
- **OFF**: Idle
- **50ms blink**: Octave shift confirmed
- **Fast blink (100ms)**: Recovery mode

---

## Firmware Architecture

### Core Components

1. **Config.h**: Pin definitions, timing constants, chord masks
2. **ChordManager**: Octave shift detection state machine
3. **LedController**: TX LED manipulation via direct port access
4. **Utils**: Debouncing, time helpers
5. **main .ino**: Setup, loop, MIDI handling

### Key Design Decisions

**No EEPROM**: Device is stateless - always boots to octave 0  
**No Control_Surface library**: Custom MIDIUSB implementation for minimal latency  
**Direct port I/O for LED**: Bypasses Arduino digitalWrite() overhead  
**Watchdog timer**: 4-second timeout prevents soft-locks  

---

## MIDI Implementation

### Note Generation

**Channel**: 1 (MIDI channel 0 in code, 1-indexed in DAWs)  
**Velocity**: Fixed at 127 (maximum)  
**Note Range**: 36-51 base, expandable to 0-127 via octave shifting

**Octave Calculation**:
```cpp
transmitted_note = BASE_NOTES[key] + (octaveShift * 12)
```

Where `octaveShift` ranges from -3 to +3.

### Debouncing

**Algorithm**: Per-key timestamp-based debouncing  
**Threshold**: 30ms (configurable via `DEBOUNCE_MS`)  
**Logic**:
1. Raw pin read differs from stable state → Start timer
2. After 30ms of consistent state → Update stable state
3. Stable state change → Send MIDI event

This prevents ghost triggers from mechanical bounce while maintaining low latency.

---

## Octave Shifting System

### Chord Trigger Mechanism

**Concept**: Pressing 6+ keys on one side simultaneously shifts octave

**Configuration** (in Config.h):
```cpp
// Left half (columns 0-1): Keys 0,1,4,5,8,9,12,13
CHORD_MASK_DOWN = 0x3333

// Right half (columns 2-3): Keys 2,3,6,7,10,11,14,15  
CHORD_MASK_UP = 0xCCCC

CHORD_THRESHOLD = 6  // Minimum keys required
```

**Detection Logic**:
1. Count active keys matching each mask
2. If ≥6 keys on LEFT side → Octave down
3. If ≥6 keys on RIGHT side → Octave up
4. Release all keys → Reset detection (can re-trigger)

**Range Limits**:
- Minimum: -3 octaves (transmitted note ≥ 0)
- Maximum: +3 octaves (transmitted note ≤ 127)

**LED Feedback**: 50ms blink on shift, 300ms debounce before next shift

---

## State Machine (ChordManager)

```
IDLE ─────────────────┐
  │                    │
  │ Detect 6+ keys     │ Cancel threshold (< 2 keys)
  ▼                    │
DEBOUNCING ───────────┘
  │
  │ Hold threshold met
  ▼
TRIGGERED ────────────┐
  │                    │
  │ Send octave shift  │ Release detected
  │ Blink LED          │
  └────────────────────┘
```

**Thresholds**:
- **Trigger**: 6/8 keys on one side
- **Cancel**: < 2 keys (return to IDLE without triggering)
- **Hold time**: 300ms to prevent accidental shifts

---

## Recovery Mode

**Purpose**: Fail-safe for soft-bricked devices (e.g., USB takeover by MIDI)

**Trigger**: Hold keys 0 AND 15 during power-on  
**Behavior**:
- Enter infinite loop with fast LED blinking
- No MIDI or USB initialization
- Exposes CDC serial for Arduino IDE bootloader access
- Exit: Power cycle or successful firmware upload

**Implementation**:
```cpp
if (digitalRead(KEY_PINS[0]) == LOW && 
    digitalRead(KEY_PINS[15]) == LOW) {
  enterRecoveryMode();  // Never returns
}
```

---

## Timing & Performance

| Metric | Value | Notes |
|---|---|---|
| Debounce time | 30ms | Per-key, tunable |
| Loop iteration | ~1ms | Varies with key count |
| MIDI transmission | Immediate | No buffering |
| Octave shift hold | 300ms | Prevents accidental triggers |
| Total latency | ~10-40ms | Debounce-dependent |

**Watchdog Timer**: 4 seconds, resets device on hang

---

## Diagnostic Utilities

The firmware repository includes testing tools (see `utils/` and `testing/`):

- **crosstalk_detector**: Tests Arduino header shorts before assembly
- **connection_scout**: Tests button connectivity and ground shorts
- **firmware_test**: Configurable test harness (toggle watchdog/MIDIUSB)

See [Diagnostic Utilities README](../../firmware/Dilla4x-MIDI/utils/README.md) for usage.

---

## Flashing Instructions

### Using Arduino IDE

1. **Install Dependencies**:
   - Arduino IDE 1.8.x or 2.x
   - Board: Arduino AVR Boards (built-in)
   - Library: MIDIUSB (via Library Manager)

2. **Configure**:
   - Tools → Board → "Arduino Leonardo" (Pro Micro compatible)
   - Tools → Port → Select your device (e.g., `/dev/ttyACM0`)

3. **Upload**:
   - Open `Dilla4x-MIDI.ino`
   - Verify (✓) to compile
   - Upload (→) to flash

### Using arduino-cli

```bash
cd firmware/Dilla4x-MIDI

# Compile
arduino-cli compile --fqbn arduino:avr:micro --warnings all ./

# Upload (replace port)
arduino-cli upload -p /dev/ttyACM0 --fqbn arduino:avr:micro ./
```

### Using Makefile

```bash
cd firmware/Dilla4x-MIDI

make compile
make upload PORT=/dev/ttyACM0
```

**Expected Build Output**:
```
Sketch uses ~19KB (66%) of program storage space
Global variables use ~1.3KB (51%) of dynamic memory
```

---

## Configuration Parameters

All in `Config.h`:

| Constant | Value | Description |
|---|---|---|
| `NUM_KEYS` | 16 | Number of buttons |
| `DEBOUNCE_MS` | 30 | Debounce threshold (ms) |
| `OCTAVE_CHORD_HOLD_MS` | 300 | Minimum hold time for octave shift |
| `MIN_OCTAVE` | -3 | Lowest octave offset |
| `MAX_OCTAVE` | 3 | Highest octave offset |
| `MIDI_CHANNEL` | 0 | MIDI channel (0-indexed) |
| `CHORD_THRESHOLD` | 6 | Keys required for octave shift |

---

## Troubleshooting

### Compilation Errors

**"MIDIUSB.h not found"**  
→ Install MIDIUSB library via Arduino Library Manager

**"Board not found"**  
→ Install Arduino AVR Boards via Boards Manager

### Upload Failures

**"Device not detected"**  
→ Use manual reset: Touch RST to GND twice quickly

**"avrdude sync error"**  
→ Check USB cable (must be data cable), try different port

### Runtime Issues

**No MIDI output**  
→ Verify DAW shows "Arduino Leonardo" or "Pro Micro" as MIDI input

**Keys not responding**  
→ Run `connection_scout` utility to test hardware

**Octave shifts not working**  
→ Ensure pressing 6+ keys on one side simultaneously

---

## Version History

**v0.3 (Current)**:
- Removed Control_Surface dependency
- Native MIDIUSB implementation
- Optimized debouncing (~30% flash savings)
- Fixed LED interference with USB communication
- Improved octave shift reliability

**v0.2**:
- Added recovery mode
- Watchdog timer implementation

**v0.1**:
- Initial Control_Surface-based implementation

---

## References

- **Full Spec**: [`FIRMWARE_SPEC.md`](../../firmware/Dilla4x-MIDI/FIRMWARE_SPEC.md)
- **User Guide**: [How to Use Your Dilla4x](../software/How-to-Use-Dilla4x-MIDI.md)

- **Hardware Assembly**: [Assembly Guide](../hardware/Assembly-Guide.md)
- **Source Code**: `firmware/Dilla4x-MIDI/`

**License**: Apache 2.0 (see LICENSE)  
**Maintainer**: See repository contributors

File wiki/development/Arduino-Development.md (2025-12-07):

# Arduino Development Setup (MIDI Firmware)

Guide for setting up the development environment for the **Dilla4x Standard MIDI Firmware (v0.3)**.

> [!NOTE]
> This guide is specific to the `firmware/Dilla4x-MIDI` codebase. Other firmwares (e.g., QMK) will use different toolchains.

## Official Resources
- [Arduino IDE Download](https://docs.arduino.cc/software/ide/)
- [Getting Started with Arduino IDE 2](https://docs.arduino.cc/software/ide-v2/tutorials/getting-started-ide-v2)
- [Downloading and Installing Guide](https://docs.arduino.cc/software/ide-v2/tutorials/getting-started/ide-v2-downloading-and-installing)

## Language References
- [Programming Guide](https://docs.arduino.cc/programming/)
- [Language Reference](https://docs.arduino.cc/language-reference/)
- [Getting Started with Arduino](https://docs.arduino.cc/learn/starting-guide/getting-started-arduino/)

## Basic Setup
1. Install Arduino IDE
2. Select Board: Arduino Leonardo
3. Install **MIDIUSB** library (not Control_Surface)
4. Upload firmware from `firmware/Dilla4x-MIDI/Dilla4x-MIDI.ino`

## Step-by-Step Firmware Upload
1. Download firmware from GitHub
2. Open `Dilla4x.ino` in Arduino IDE
3. Select Tools > Board > Arduino Leonardo
4. Select correct USB port
5. Click Upload button (→ icon)

## Next Steps
- [Firmware Configuration](Dilla4x_Firmware.md)
- [Advanced Development with VSCodium](VSCodium-PlatformIO-MIDI-Guide.md)

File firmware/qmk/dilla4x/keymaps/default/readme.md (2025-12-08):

# Default Keymap (Web-Dilla Compatible)

Standard alphanumeric layout optimized for the **Web-Dilla4x** sampler.

## Features
- **Plug & Play**: Works instantly with `tools/web-dilla4x/index.html` default mapping.
- **Macropad Ready**: Sends standard keystrokes (1-4, Q-R, A-F, Z-V).
- **VIA Support**: Remap keys instantly using [VIA](https://usevia.app).
- **Layer Support**: Dynamic layers available via VIA.

## Layout

| | Col 1 | Col 2 | Col 3 | Col 4 |
|---|---|---|---|---|
| **Row 0** | 1 | 2 | 3 | 4 |
| **Row 1** | Q | W | E | R |
| **Row 2** | A | S | D | F |
| **Row 3** | Z | X | C | V | MIDI 44-47
├─────┼─────┼─────┼─────┤
│ E2  │ F2  │ F#2 │ G2  │  MIDI 40-43
├─────┼─────┼─────┼─────┤
│ C2  │ C#2 │ D2  │ D#2 │  MIDI 36-39
└─────┴─────┴─────┴─────┘

This layout is NOT configurable at runtime. For customization, use the VIA keymap.

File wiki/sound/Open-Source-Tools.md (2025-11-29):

# Open Source Music Toolkit

## Essential Tools
### DAWs (Full Studios)
- [Ardour](https://ardour.org/) - Professional recording/mixing (Win/Mac/Linux)
- [LMMS](https://lmms.io/) - Beat making & electronic music (Win/Mac/Linux)
- [Zrythm](https://www.zrythm.org/) - Modern workflow with automation
- [BespokeSynth](https://www.bespokesynth.com/) - Modular patching environment

### Synths (Sound Creators)
- [Surge XT](https://surge-synthesizer.github.io/) - All-in-one synth (1800+ presets)
- [Helm](https://tytel.org/helm/) - Easy subtractive synth
- [Odin 2](https://www.thewavewarden.com/odin2) - Powerful polyphonic synth
- [Dexed](https://asb2m10.github.io/dexed/) - Classic FM synth (DX7 style)

### Drums & Samples
- [Hydrogen](https://hydrogen-music.org/) - Pattern-based drum machine
- [DrumGizmo](https://www.drumgizmo.org/) - Realistic acoustic drums
- [sfizz](https://github.com/sfztools/sfizz) - SFZ sample player

### Helpful Utilities
- [Carla](https://kx.studio/Applications:Carla) - Plugin host for instrument racks
- [Stochas](https://stochas.org/) - Smart MIDI sequencer
- [Sonic Pi](https://sonic-pi.net/) - Code-based music creation
- [Strudel](https://strudel.cc/) - Web-based live-coding (TidalCycles port) with immediate feedback

## Platform Support
| Tool | Windows | macOS | Linux |
|---|---|---|---|
| Ardour | ✓ | ✓ | ✓ |
| LMMS | ✓ | ✓ | ✓ |
| Surge XT | ✓ | ✓ | ✓ |
| Hydrogen | ✓ | ✓ | ✓ |
| Sonic Pi | ✓ | ✓ | ✓ |
| Strudel | ✓ | ✓ | ✓ |

## Starter Packs
### Beginner Friendly
1. [LMMS](https://lmms.io/) - Simple beat making
2. [Helm](https://tytel.org/helm/) - Easy synth
3. [Hydrogen](https://hydrogen-music.org/) - Drum patterns

### Recording Focused
1. [Ardour](https://ardour.org/) - Multi-track recording
2. [Surge XT](https://surge-synthesizer.github.io/) - Versatile sounds
3. [DrumGizmo](https://www.drumgizmo.org/) - Real drums

### Experimental
1. [BespokeSynth](https://www.bespokesynth.com/) - Modular environment
2. [Carla](https://kx.studio/Applications:Carla) - Plugin host
3. [Stochas](https://stochas.org/) - Creative sequencer
4. [Strudel](https://strudel.cc/) - Pattern-based live coding environment

## Quick Tips
- Start small: Limit to 3-4 tracks at first
- Use templates: Pre-made project starters help
- Save versions: Keep different song iterations
- Hide complex panels: Focus on basics first

👉 [Back to Music Overview](Music-Making-Overview.md)

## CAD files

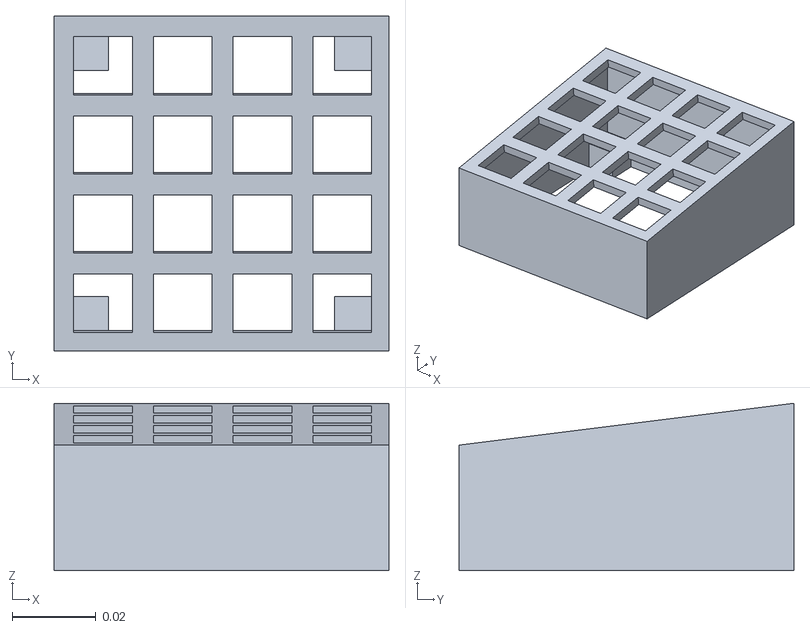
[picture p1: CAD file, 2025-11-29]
Parts/V0.1/Dilla4x v0.1 - Top v0.1.stl
0.08 x 0.08 x 0.04

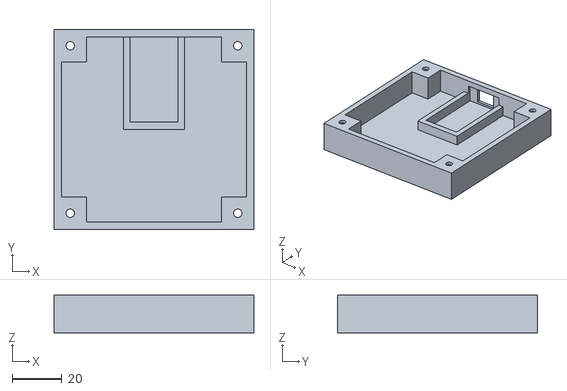
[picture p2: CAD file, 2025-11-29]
Parts/V0.1/Dilla4x v0.1 - Bottom v0.5.stl
80.0 x 80.0 x 15.0

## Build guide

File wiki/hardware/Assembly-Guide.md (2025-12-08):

# Dilla4x Assembly Guide

> **Before starting:**
> - Ensure you have the [latest 3D printed parts](3D-Printing-Guide.md)
> - Verify all pieces are clean and undamaged

## Step 1: Assembling the 3D Printed Shell

### Check the Parts
1. **Inspect All Pieces**:
   - Examine the top and bottom plates
   - Ensure all heated inserts (metal pieces inside the plates) are present and properly placed

2. **Clean the Parts**:
   - Remove any leftover material from printing (small blobs/strings) to ensure smooth assembly

### Assemble the Plates
1. **Position the Plates**:
   - Place the top plate on top of the bottom plate, aligning them correctly
   - Match all screw hole positions precisely

2. **Secure with Screws**:
   - Use M3 screws through heated inserts
   - Tighten in diagonal pattern (like lug nuts) for even pressure
   - Tighten firmly but avoid over-tightening to prevent damaging plates

### Final Checks
- **Stability**: Ensure plates are securely attached with no wobble
- **Accessibility**: Confirm USB-C port is fully exposed and aligned
- **Inspection**: Verify no cracks or deformations in plastic

## Step 2: Electronic Components Setup

### Component Overview
1. **Arduino Pro Micro**:
   - The brain of your MIDI controller (ATmega32U4 @ 16MHz)
   - Handles all key inputs and MIDI communication

2. **Cherry MX Keyswitches**:
   - Mechanical switches with 4mm travel distance
   - Linear Red variant (no tactile bump)

3. **Dupont Connectors**:
   - Jumper wires for solderless connections
   - Secure crimp connections for reliable operation

### Quality Assurance Testing (Critical for DIY Builds)

Two types of shorts can occur during assembly, and each has its own diagnostic tool:

---

#### **BOTTOM SECTION TEST: Arduino Header Shorts** (Crosstalk Detector)

> [!IMPORTANT]
> **Run this test IMMEDIATELY after soldering headers** - before installing Arduino in bottom tray, before attaching any buttons.

**What This Tests**: Solder bridges between Arduino Pro Micro header pins

**Why It Matters**:
- Solder whiskers/bridges under rubber spacers are invisible from top
- Header shorts cause multiple keys to trigger together ("crosstalk")
- Testing before assembly = easy fix; testing after = full disassembly required
- **Real failure mode**: Under magnification, header joints may look clean, but traces can be shorted underneath the board on the OTHER side

**Testing Procedure**:

1. **Upload `crosstalk_detector.ino`**:
   - Located in firmware utilities folder
   - Upload to freshly-soldered Arduino (no buttons attached yet)
   - Open Serial Monitor at 115200 baud

2. **Read the Results**:
   - **✅ PASS**: `Status: Clean (No Crosstalk Detected)` → Safe to install in tray
   - **❌ FAIL**: `SHORT DETECTED: Pin X <---> Pin Y` → Rework needed

3. **If Shorts Detected**:
   - Check BOTH sides of the board (top solder joints AND traces underneath)
   - Remove solder bridges with desoldering wick/braid
   - Inspect under rubber spacers for hidden shorts
   - Re-test until completely clean
   - Flash main firmware only after passing

**How it works**: Systematically drives each pin LOW and checks if neighboring pins follow (indicating physical connection). Detects solder blobs, whiskers, flux contamination, and PCB trace damage.

> [!WARNING]
> **Even if solder joints look perfect**, shorts can exist underneath. The rubber spacers on Arduino boards can hide damaged traces. Always run this test.

### Mount Arduino Pro Micro
1. **Placement**:
   - Insert into designated space on bottom plate
   - Orient USB-C port toward housing opening
   - Ensure no components contact metal inserts

2. **Securing**:
   - Apply small dots of hot glue to board edges
   - Avoid covering USB port, reset button, or components
   - Let glue cure for 5 minutes before handling

### Connect Keyswitches

**Complete Pin Assignments**:
| Key | Pin | Key | Pin  |
|-----|-----|-----|---|
| K1  | 2 | K9  | 10 |
| K2  | 3 | K10 | 11 |
| K3  | 4 | K11 | 12 |
| K4  | 5 | K12 | 13 |
| K5  | 6 | K13 | A0 |
| K6  | 7 | K14 | A1 |
| K7  | 8 | K15 | A2 |
| K8  | 9 | K16 | A3 |

**Detailed Wiring Instructions**:
1. **Main Keys (K1-K12)**:
   - Connect each key to its digital pin using Dupont connectors:
     - Example: K1 → Pin 2 (attach female connector to switch, male to Arduino)
   - Follow numerical order from left to right, top to bottom
   - Keep wires taut but not stretched

2. **Analog Keys (K13-K16)**:
   - Connect to analog pins:
     - K13 → A0 (white wire recommended)
     - K14 → A1 (green wire recommended)
     - K15 → A2 (blue wire recommended)
     - K16 → A3 (yellow wire recommended)
   - Route these wires separately from digital lines

3. **Cable Management**:
   - Use small zip ties every 2 inches
   - Route wires along channel edges
   - Leave slight service loop near Arduino
   - Ensure no wires are pinched or under tension

## Step 3: Final Assembly

### Install Keyswitches
1. **Mount Switches**:
   - Press Cherry MX switches into top plate until they click
   - Confirm all switches sit flush with plate
   - Verify proper orientation (LED notch facing correct direction)

2. **Attach Keycaps**:
   - Align keycap stems with switch tops
   - Press firmly until they snap into place
   - Test each key for smooth operation

### Housing Closure
1. **Pre-Close Checklist**:
   - Verify no pinched wires
   - Confirm Arduino position is maintained
   - Test all key actions before sealing
   - Ensure USB cable can be inserted/removed freely

2. **Secure Housing**:
   - Align plates precisely
   - Insert and tighten all 16 screws gradually in star pattern
   - Final torque check after 24 hours (retighten if needed)

## Post-Assembly Verification
1. **Physical Test**:
   - All keys press smoothly with 4mm travel
   - No creaking or flex in housing
   - USB cable inserts/removes easily
   - No visible gaps between plates

2. **Electrical Test**:
   - Connect to computer - verify power LED illuminates
   - Check for unexpected warmth from components
   - Listen for any buzzing or crackling sounds
   
3. **Functional Testing**:
   
   **Quick Test**: Flash main firmware and test each key in your DAW or MIDI monitor software
   
   **Thorough QA** (Recommended for builders):
   - The firmware utilities include a tool called **`connection_scout`** for systematic testing
   - Upload it to your assembled device (see "Reflashing" below if main firmware is already loaded)
   - Open serial monitor (115200 baud)
   - Press each button - it will show which pin activated
   - Verify all 16 keys respond and map to correct pins
   - Check for "ghost triggers" (buttons activating without being pressed)
   
   **Expected result**: Each button press should show `ACTIVITY DETECTED ON PIN: X` with the correct pin number for that button position.
   
   If buttons don't respond or trigger wrong pins, check your Dupont connector wiring against the pin assignment table above.

---

## Troubleshooting: Keyswitch Ground Shorts

> [!WARNING]
> **TOP SECTION SHORTS - Common production issue**

**Problem**: Keyswitch positive pin shorted to ground, causing key to be "always pressed" or completely dead.

**Causes**:
- **Bare ground wire retaining heat**: Sinks through hot glue, contacts positive pin
- **Solid core wire overheating**: Wire melts through switch housing, shorting internally
- **Poor strain relief**: Hot glue not fully bonding, allowing wire movement and contact

**Symptoms**:
- Key appears "stuck" (always triggered)
- Key completely unresponsive
- Random triggering without physical press

#### **TOP SECTION TEST: Keyswitch Ground Shorts** (Connection Scout)

> [!IMPORTANT]
> Run this AFTER full assembly if keys behave strangely

**Testing Procedure**:

1. **Upload `connection_scout.ino`**:
   - May require manual reset (see "Reflashing" below)
   - Open Serial Monitor at 115200 baud

2. **Observe Behavior**:
   - **✅ GOOD**: Pin only shows activity when button physically pressed
   - **❌ BAD**: Pin shows continuous `[PIN X:0!]` without button press = shorted to ground

3. **Fix Ground Shorts**:
   - Disassemble housing
   - Inspect suspect keyswitch solder joints
   - Check for:
     - Bare ground wire touching positive pin
     - Wire sunk into switch housing
     - Failed hot glue strain relief
   - Re-solder with proper insulation and strain relief
   - Allow ALL joints to fully cool before moving wires

---

## Reflashing Diagnostic Utilities (Manual Reset Procedure)

> [!CAUTION]
> **If main firmware is already running**, the device may "soft-brick" - USB taken over by MIDI, preventing normal uploads.

**When you need this**: Uploading `crosstalk_detector` or `connection_scout` after main firmware is installed

**Manual Reset Procedure**:

1. **Open the Device**:
   - Remove screws from housing
   - Separate top and bottom sections
   - Locate Arduino Pro Micro

2. **Access Reset Pin**:
   - Find RST pad/pin on Arduino (near USB port)
   - Find GND pad/pin or any ground point

3. **Trigger Bootloader**:
   - Have upload ready in Arduino IDE (click Upload button)
   - **Quickly touch RST to GND TWICE** (double-tap within 1 second)
   - Arduino enters bootloader mode (8 second window)
   - IDE should detect port and upload immediately

4. **Alternative Method**:
   - Touch RST to GND once to reset
   - Within 8 seconds, click Upload in IDE
   - Repeat if timeout occurs

> [!TIP]
> **Use a bent paperclip or spare wire** to bridge RST and GND. Practice the timing before having a sketch ready to upload.

> [!NOTE]
> **Future hardware improvement**: Roadmap includes adding a reset button access hole in bottom plate to eliminate disassembly requirement.

👉 Next: [Arduino Development Guide](../development/Arduino-Development.md) or [How to Use Your Dilla4x](../software/How-to-Use-Dilla4x-MIDI.md)
⚠️ **Important**: Complete software setup before first use!

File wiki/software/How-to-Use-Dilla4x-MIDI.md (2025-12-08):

# How to Use Your Dilla4x (MIDI Firmware)

A simple, accessible guide to playing and controlling your Dilla4x using the **standard MIDI Firmware (v0.3)**.

> [!NOTE]
> This guide applies to the **Dilla4x-MIDI firmware (v0.3.0)**. For the QMK firmware, see the [Dilla4x-QMK Guide](How-to-Use-Dilla4x-QMK.md).

## What the Dilla4x Does (In Plain English)

The Dilla4x is a **16-button MIDI controller** that sends musical notes to your computer. Think of it like a tiny piano keyboard, but arranged in a 4x4 grid instead of the traditional piano layout.

**What makes it special**:
- Each button plays a different musical note
- You can shift all notes up or down (octave shifting)
- It's designed to be playable with limited hand mobility
- Works instantly with any music software that accepts MIDI

---

## Button Layout & Notes

### The Grid

Your Dilla4x has 16 buttons arranged like this:

```
[K1 ] [K2 ] [K3 ] [K4 ]    ← Row 1 (Top)
[K5 ] [K6 ] [K7 ] [K8 ]    ← Row 2
[K9 ] [K10] [K11] [K12]    ← Row 3
[K13] [K14] [K15] [K16]    ← Row 4 (Bottom)
```

### What Notes They Play

**Starting notes** (before any octave shifting):

```
Row 1:  C3   C#3  D3   D#3     (Highest notes)
Row 2:  G#2  A2   A#2  B2
Row 3:  E2   F2   F#2  G2
Row 4:  C2   C#2  D2   D#2     (Lowest notes)
```

**Musical pattern**: The notes are arranged chromatically (every half-step) going from bottom-left to top-right, like climbing a musical ladder.

---

## How to Play

### Basic Playing (Individual Notes)

**Press any button** = That note plays (MIDI "Note On")  
**Release the button** = Note stops (MIDI "Note Off")

**For playing individual notes**, use precise fingertip presses - just like piano keys.

### Playing Techniques

#### **For Individual Notes**:
- Use **fingertips** to press buttons precisely
- One finger per button for single notes
- Multiple fingers for chords (pressing several buttons intentionally)
- This is standard playing - requires some finger dexterity

#### **For Octave Shifting** (Accessible):
This is where the accessibility design shines - octave shifting can be done with minimal dexterity:

1. **Flat Finger Method**:
   - Lay 1-2 fingers **flat** across one side (left or right half)
   - Press down to activate multiple buttons at once
   - Good for limited finger dexterity

2. **Palm/Hand Side Method**:
   - Use the **side of your hand** or **palm edge**
   - Press down on one entire half of the grid
   - Excellent for users with limited fine motor control
   - Most accessible option - requires zero finger precision

> [!IMPORTANT]
> **The flat finger and palm methods are for OCTAVE SHIFTING, not normal playing.** You can't hit individual keys accurately with your palm - these techniques are specifically designed for the "chord trigger" that shifts octaves.

**Summary**:
- **Normal playing** = Fingertips on individual buttons
- **Octave shifting** = Flat fingers or palm on entire left/right half

---

## Octave Shifting: Making Notes Higher or Lower

This is where the Dilla4x gets powerful. You can shift **all** the notes up or down by octaves.

### What's an Octave?

An octave is the distance from one note to the same note at a higher/lower pitch. For example:
- C2 → C3 = +1 octave (higher)
- C3 → C2 = -1 octave (lower)

When you shift octaves, all 16 buttons play notes that are higher or lower, but keep the same pattern.

### How to Shift Octaves

#### **Shift UP** (Make Notes Higher)

**Press the RIGHT HALF** of your Dilla4x (all 8 right-side buttons at once):

```
        [✓] [✓]    ← These 8 buttons
        [✓] [✓]
        [✓] [✓]
        [✓] [✓]
```

**How to do it**:
1. Place your hand flat on the **right side** of the grid
2. Press down with your **palm or multiple fingers**
3. Press **at least 6 of the 8 right buttons** at the same time
4. The LED will blink once to confirm
5. All notes are now **one octave higher**

#### **Shift DOWN** (Make Notes Lower)

**Press the LEFT HALF** of your Dilla4x (all 8 left-side buttons at once):

```
[✓] [✓]        ← These 8 buttons
[✓] [✓]
[✓] [✓]
[✓] [✓]
```

**How to do it**:
1. Place your hand flat on the **left side** of the grid
2. Press down with your **palm or multiple fingers**  
3. Press **at least 6 of the 8 left buttons** at the same time
4. The LED will blink once to confirm
5. All notes are now **one octave lower**

### Octave Range

- You can shift **3 octaves up** (maximum)
- You can shift **3 octaves down** (minimum)
- That gives you a total range of **7 octaves** to work with!

**Example**: If you start at C2 and shift up 3 times, you'll be at C5. That's a huge musical range from a tiny controller!

### Octave Reset

**What if you forget what octave you're in?**

1. Unplug the Dilla4x
2. Plug it back in
3. It **always starts at octave 0** (middle range)

This "reset to zero" design means you never get "lost" - just power cycle to get back to the default.

---

## Understanding the LED Feedback

The Dilla4x has a built-in LED that tells you what's happening:

| LED Behavior | What It Means |
|---|---|
| **Solid ON** | You're pressing a button (note playing) |
| **OFF** | No buttons pressed (idle) |
| **Quick blink** | Octave shift confirmed |
| **Fast continuous blinking** | Recovery mode (troubleshooting only) |

The LED gives you visual confirmation that your octave shifts worked, which is helpful when you're performing live.

---

## Common Usage Patterns

### For Beat Making (Drums)
- Keep at octave 0 or shift down 1-2 octaves for deep bass hits
- Use palm strikes for powerful drum sounds
- Quick taps with fingers for hi-hats and percussion

### For Melodies
- Shift up 1-2 octaves for lead lines
- Use fingertips for precise note control
- Experiment with different octave ranges for variety

### For Basslines
- Shift down 2-3 octaves for sub-bass
- Use flat fingers or palm for thick, chorded bass
- Lower notes have more power and weight

### For Accessibility
- Use whatever playing technique works for you
- Palm/hand side method requires **zero fine motor control**
- Octave shifting lets you access the full musical range without repositioning your hand

---

## Troubleshooting

### "My octave shifts aren't working"

**Requirement**: You need to press **at least 6 out of 8 buttons** on one side.

**Try this**:
- Press with your **whole palm** flat on one side
- Make sure you're covering the full half of the grid
- You should feel/see at least 6 buttons actually clicking down

### "I don't know what octave I'm in"

**Solution**: Unplug and replug the Dilla4x - it always resets to octave 0.

### "Some notes sound wrong"

The Dilla4x uses **chromatic tuning** (all half-steps). Not every series of buttons will sound "musical" - that's intentional! You're working with raw musical intervals.

For traditional scales (major, minor, etc.), you'll skip some buttons. That's normal.

---

## Tips for New Users

1. **Start simple**: Just press buttons and hear what they sound like before worrying about octaves

2. **Experiment with technique**: Try fingers, flat hand, and palm - find what feels best

3. **Use your DAW's piano roll**: See which notes you're playing and learn the layout

4. **Practice octave shifts**: Get comfortable with the palm-press motion - it becomes second nature

5. **Don't overthink it**: The Dilla4x is designed to be intuitive. If it makes sound when you press it, you're doing it right!

---

## Advanced: Why These Design Choices?

### Chromatic Layout
The Dilla4x uses **all 12 notes** (chromatic scale) rather than just white keys like a piano. This gives you:
- Complete musical freedom (any scale, any key)
- Ability to play notes between major scale steps
- Maximum flexibility for non-Western musical traditions

### Accessibility First
The octave shift via "chord trigger" (pressing multiple buttons) was designed so that:
- Users with limited fingers can shift octaves with their palm
- No need for extra buttons or complex menus
- Physical motion is the same as playing (press buttons)
- Visual/tactile feedback (LED blink) confirms the action

### Stateless Design
The device **resets to zero** on power-up intentionally:
- You always know where you're starting from
- No confusion about saved states
- Simple mental model: plug in = octave 0

---

## Getting Started Checklist

1. ✅ Plug Dilla4x into computer via USB
2. ✅ Open your music software (DAW, synthesizer, etc.)
3. ✅ Select "Dilla4x" or "Arduino Pro Micro" as MIDI input
4. ✅ Press a button - hear a sound!
5. ✅ Practice octave shifts (palm press left/right halves)
6. ✅ Make music! 🎵

---

**Remember**: The Dilla4x is a tool for making music **your way**. There's no right or wrong technique - use what works for your hands and your music.

👉 Next: [Connecting to Your DAW](../sound/Music-Making-Overview.md)  
🎵 Also See: [Beginner Music Making Tips](../sound/Beginner-Guide.md)

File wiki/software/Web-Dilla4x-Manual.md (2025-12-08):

# Web Dilla4x Manual

**Web Dilla4x** is the official companion web app for the Dilla4x MIDI controller. It features a dual-mode engine: a versatile **Sampler** for chopping samples and a powerful **Synth** for playing melodies.

## Getting Started
1.  **Open the App**: Open the `index.html` file located in `tools/web-dilla4x/` in a modern browser (Chrome, Edge, or Brave recommended for Web MIDI support).
2.  **Connect MIDI**: Plug in your Dilla4x controller via USB.
    *   **Auto-Detect**: The status bar will show "MIDI Ready". The app automatically attempts to detect if you are using QMK or the custom DillaFW and adjusts the mapping accordingly.
    *   *Manual Override*: If the mapping feels wrong (e.g. pads are scattered), manually select "QMK" or "DillaFW" from the dropdown in the toolbar.
3.  **Start Audio**: Click anywhere on the page or press a pad to initialize the audio engine.

## Interface Overview
*   **Toolbar**: Access global controls like Load/Save, Main Volume, Mode Switching, and Theme toggles.
*   **The Grid**: A 4x4 interactive representation of your controller pads.
*   **Visualizer**: A real-time oscilloscope and VU meter at the bottom of the screen to visualize your sound.
*   **Sidebar**: A sliding settings panel that changes based on your current Mode and selection. Open it by clicking the "⚡ Settings" button or switching modes.

---

## Mode: Sampler
The default mode. Designed for playing one-shot samples, drums, and FX.

### 1. Loading Samples
*   **Drag & Drop**: Simply drag any audio file (`.wav`, `.mp3`, `.ogg`) from your computer onto a specific pad to load it instantly.
*   **Load Pack**: Click the "Load Pack" button to import a `.dilla` or `.zip` file containing up to 16 audio files.
*   **Global Drag**: Drag a `.dilla` or `.zip` pack anywhere onto the page background to load the entire kit at once.

### 2. Per-Pad Settings
Every pad has its own independent settings. To edit a pad, **click it** or **press it** on your controller. The Sidebar will update to show:
*   **Pitch**: Change the playback speed and pitch of the sample (0.1x to 2.0x).
*   **Attack**: Fade-in time. Increase this to soften the start of the sound (e.g. for pads or swells).
*   **Decay**: Controls how long the sample sustains. Lower this to make the sound "tighter" or "shorter".

### 3. Renaming Pads
Organize your kit by renaming pads directly.
1.  **Click** the text label on any pad (e.g., "Empty" or the filename).
2.  **Type** your new name.
3.  **Press Enter** or click away to save.

---

## Mode: Synth
Switch to **Synth Mode** using the dropdown in the toolbar to turn your Dilla4x into a melodic instrument.

### Sound Design Controls
The Sidebar provides a full subtractive synthesis engine:
*   **Waveform**: Choos between **Triangle** (mellow), **Sine** (smooth), **Square** (retro/chiptune), and **Sawtooth** (bright/edgy).
*   **Vibrato**: Adds a pulsating pitch modulation effect (LFO). Great for lead sounds.
*   **Volume**: Master volume for the synth engine.
*   **Envelope (ADSR)**:
    *   *Attack*: How fast the sound reaches full volume.
    *   *Release*: How long the sound fades out after you let go of the key.
*   **Filter**: A Low-Pass Filter to shape the brightness.
    *   *Cutoff*: Frequencies above this point are removed.
    *   *Resonance (Q)*: Emphasizes the cutoff frequency for a "squelchy" sound.

### Keyboard Layouts
You can change the note mappings in the sidebar:
*   **MPC (Up)**: Notes align chromatically starting from the bottom-left (C3) and going up. Best for melodic playing.
*   **Book (Down)**: Notes read left-to-right, top-to-bottom.

---

## Global Features

### Main Volume
A master volume slider is available in the top toolbar to control the overall output level of the app.

### Visualizer & VU Meter
*   **Oscilloscope**: The waveform display shows the shape of your sound in real-time.
*   **VU Meter**: The vertical bar next to the visualizer shows your output levels. Keep it in the green/yellow!

### Theme & Accent
*   **Dark/Light Mode**: Toggle the Sun/Moon icon to switch themes.
*   **Accent Color**: Click the color circle to pick a custom LED/Accent color for the interface. This preference is saved automatically.

### Saving Your Work
*   **Save Pack**: Click this to download your current bank of samples as a `.dilla` file. You can share this file with others or load it back later. *Note: Synth settings are not currently saved in packs.*

## Keyboard Shortcuts
Don't have your MIDI controller? You can play using your computer keyboard:
*   **Row 1**: `1` `2` `3` `4`
*   **Row 2**: `Q` `W` `E` `R`
*   **Row 3**: `A` `S` `D` `F`
*   **Row 4**: `Z` `X` `C` `V`

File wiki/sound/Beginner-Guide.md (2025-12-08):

# Easiest Ways to Make Music

## A. All-in-One Web/Mobile Studio
**BandLab**  
[https://www.bandlab.com/](https://www.bandlab.com/)  
- Full studio in browser/phone
- Drag loops, record vocals/instruments
- No driver setup or plugin installation

## A. Instant Play (No Installation)
**Web Dilla4x**  
*Included with your Dilla4x*  
- **zero setup**: Open the HTML file and start playing 
- **Dual Mode**: Switch between a Sampler (for drums) and Synth (for melodies)
- **Learn basics**: Great for understanding envelopes, filters, and pitch without complex software
- [Read the Manual](../software/Web-Dilla4x-Manual.md)

## B. All-in-One Web/Mobile Studio
**BandLab**  
**SunVox**  
[https://warmplace.ru/soft/sunvox/](https://warmplace.ru/soft/sunvox/)  
- Modular synth + pattern sequencer
- Runs on all platforms
- Free desktop version

**Sonic Pi**  
[https://sonic-pi.net/](https://sonic-pi.net/)  
- Live coding environment
- Built-in tutorials
- Accessible design

## C. Simple Recording Editor
**Audacity**  
[https://www.audacityteam.org/](https://www.audacityteam.org/)  
- Record/edit multiple tracks
- Apply effects
- No MIDI required

👉 Next: [How to Use Your Dilla4x](../software/How-to-Use-Dilla4x-MIDI.md) or [Gentler DAWs](../sound/Intermediate-Guide.md)

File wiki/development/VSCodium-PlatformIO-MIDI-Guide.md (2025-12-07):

# VSCodium + PlatformIO Guide (MIDI Firmware)

Development guide for the **Dilla4x Standard MIDI Firmware**.

> [!NOTE]
> This workflow applies to the C++ based Arduino firmware. QMK development will differ.

## Installation
1. **Install VSCodium**:
   - Download from [https://vscodium.com](https://vscodium.com)
   - Follow OS-specific installation instructions

2. **Add PlatformIO IDE**:
   - Open Extensions view (Ctrl+Shift+X)
   - Search for "PlatformIO IDE" and install
   - Restart VSCodium when prompted

## Project Setup
1. **Create New Project**:
   - Open PlatformIO Home (click alien icon)
   - Select "Arduino Leonardo" as board
   - Choose "Arduino" framework

2. **Import Existing Code**:
   - Copy your `.ino` file contents into `src/main.cpp`
   - Place libraries in `lib/` directory

## PlatformIO Resources
- [Official Documentation](https://docs.platformio.org/en/latest/)
- [Arduino Debugging Tutorial](https://docs.platformio.org/en/stable/tutorials/espressif32/arduino_debugging_unit_testing.html)
- [VSCode Integration Guide](https://docs.platformio.org/en/latest/integration/ide/vscode.html)

## Workflow
- Build: Checkmark icon
- Upload: Right arrow icon
- Clean: Recycle bin icon
- Serial Monitor: Plug icon

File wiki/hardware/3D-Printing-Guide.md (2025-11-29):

# 3D Printing Guide

## Current Enclosure Files
The latest 3D printable enclosure files are available in the main repository:
- [Dilla4x-Top.stl](../../3d-prints/main/Dilla4x-Top.stl)
- [Dilla4x-Bottom.stl](../../3d-prints/main/Dilla4x-Bottom.stl)

## File Organization
- **/3d-prints/main** - Current production files
- **/3d-prints/archive** - Previous versions for reference

## Printing Recommendations
- **Material**: PLA (recommended for ease of printing)
- **Layer Height**: 0.2-0.3mm (typical range)
- **Infill**: 15-25% 
- **Supports**: Needed, recommend tree supports touching build plate only
- **Bed Adhesion**: Use brim if needed for warping

## Version History
*Check GitHub Releases for official version history*

👉 Next: [Assembly Guide](Assembly-Guide.md)

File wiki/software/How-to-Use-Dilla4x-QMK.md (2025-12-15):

# How to Use Dilla4x-QMK Firmware

> [!CAUTION]
> **QMK v0.1.1-alpha - NOT TESTED ON HARDWARE**: This firmware includes significant matrix configuration changes that have not been validated on physical hardware. All devices were sent to participants before testing could be completed. Use with caution and please report any issues.

The **Dilla4x-QMK** firmware transforms your Dilla4x into a fully programmable input device with real-time customization via VIA. This guide covers everything from flashing to advanced usage.

---

## 📋 Table of Contents

1. [What is the QMK Firmware?](#what-is-the-qmk-firmware)
2. [Flashing the Firmware](#flashing-the-firmware)
3. [Default Keymap](#default-keymap)
4. [Using VIA for Customization](#using-via-for-customization)
5. [Use Cases](#use-cases)
6. [Keyboard Shortcuts Reference](#keyboard-shortcuts-reference)
7. [Troubleshooting](#troubleshooting)
8. [Advanced Customization](#advanced-customization)

---

## What is the QMK Firmware?

**QMK (Quantum Mechanical Keyboard)** is an open-source keyboard firmware used by thousands of custom keyboards worldwide. The Dilla4x-QMK firmware (v0.1.1-alpha) brings this powerful ecosystem to your device.

### Key Differences from MIDI Firmware

| Feature | Dilla4x-MIDI (v0.3.0) | Dilla4x-QMK (v0.1.1-alpha) |
|---|---|---|
| **Primary Use** | MIDI controller for music | Programmable macro pad / gaming |
| **Customization** | Fixed layout, octave shifting via chords | Fully reprogrammable via VIA |
| **MIDI Support** | Full MIDI functionality | Optional MIDI mode |
| **N-Key Rollover** | No | Yes (gaming) |
| **Mouse Control** | No | Yes |
| **Media Keys** | No | Yes |
| **Layers** | Single layer | Unlimited (via VIA) |
| **Best For** | Music production, DAWs | Gaming, productivity, accessibility |

### When to Use QMK Firmware

Choose QMK if you want to:
- **Game**: Use as a custom gaming keypad with macros
- **Work**: Create productivity shortcuts (copy/paste, app switching, etc.)
- **Accessibility**: Remap keys for comfort or adaptive needs
- **Mix Modes**: Switch between MIDI, gaming, and macro functions

---

## Flashing the Firmware

### Prerequisites

You'll need:
- **QMK Toolbox** (Windows/Mac) or **QMK CLI** (Linux/Mac)
- **Dilla4x hardware** assembled and connected
- **Firmware file**: Pre-compiled `.hex` or build from source

### Option 1: Using QMK Toolbox (Easiest - Windows/Mac)

1. **Download QMK Toolbox**:
   - Visit: https://github.com/qmk/qmk_toolbox/releases
   - Download the latest release for your OS

2. **Get the Firmware**:
   - **Pre-compiled**: Check [Releases](https://github.com/Cypaloma/Dilla4x/releases) for `dilla4x_via.hex`
   - **Build from source**: See [QMK README](../../firmware/qmk/dilla4x/readme.md)

3. **Flash**:
   - Open QMK Toolbox
   - Click "Open" and select `dilla4x_via.hex`
   - Check "Auto-Flash"
   - **Enter bootloader** on your Dilla4x:
     - **Method 1**: Hold top-left key while plugging in USB (Bootmagic)
     - **Method 2**: Bridge RST to GND twice quickly on Pro Micro
   - Toolbox will detect and flash automatically
   - Wait for "Flash complete" message

### Option 2: Using QMK CLI (Linux/Mac/Advanced)

1. **Install QMK CLI**:
   ```bash
   # macOS
   brew install qmk/qmk/qmk
   
   # Linux
   python3 -m pip install --user qmk
   ```

2. **Setup QMK Environment**:
   ```bash
   qmk setup
   ```

3. **Link Dilla4x to QMK**:
   ```bash
   cd ~/Dilla4x
   ln -s "$(pwd)/firmware/qmk/dilla4x" ~/qmk_firmware/keyboards/dilla4x
   ```

4. **Compile and Flash**:
   ```bash
   # Compile VIA keymap
   qmk compile -kb dilla4x -km via
   ```
  4. **Flash**:
   - Run the command: `qmk flash -kb dilla4x -km via`
   - **IMPORTANT**: When prompted `Please reset your keyboard into bootloader mode now!`, you must **manually double-tap the reset button**.
   - *Note: The `auto_flash.bat` recovery script DOES NOT work for QMK flashing.*

5. **Done**: The device will restart as a QMK keyboard.

### Verification

After flashing:
1. Unplug and replug your Dilla4x
2. Open a text editor
3. Press some keys - you should see MIDI note keycodes or letters (depending on keymap)
4. The device is now running QMK firmware!

---

## Default Keymap

The default VIA keymap starts with **MIDI notes** matching the standard Dilla4x-MIDI layout:

```
┌─────┬─────┬─────┬─────┐
│ C3  │ C#3 │ D3  │ D#3 │  MIDI 48-51
├─────┼─────┼─────┼─────┤
│ G#2 │ A2  │ A#2 │ B2  │  MIDI 44-47
├─────┼─────┼─────┼─────┤
│ E2  │ F2  │ F#2 │ G2  │  MIDI 40-43
├─────┼─────┼─────┼─────┤
│ C2  │ C#2 │ D2  │ D#2 │  MIDI 36-39
└─────┴─────┴─────┴─────┘
```

**This is just the starting point!** With VIA, you can remap these to anything.

---

## Using VIA for Customization

**VIA** is a web-based configurator that lets you remap keys in real-time without reflashing firmware.

### Setting Up VIA

1. **Flash VIA Keymap** (if not already done):
   - Follow the [Flashing section](#flashing-the-firmware) above
   - Make sure you flashed the **`via`** keymap, not `default`

2. **Open VIA Configurator**:
   - Visit: https://usevia.app/
   - Use **Chrome** or **Edge** (required for Web HID)

3. **First Time Setup**:
   - Click "Authorize device" when prompted
   - Select "Dilla4x Controller" from the list
   - **NOTE**: If not detected, see [VIA Setup Guide](../../firmware/qmk/dilla4x/keymaps/via/VIA_SETUP.md)

### Remapping Keys

1. **Select a Key**:
   - Click any key on the visual layout

2. **Choose New Function**:
   - Browse the tabs: Basic, Media, Macro, Layers, Special
   - Click the desired function

3. **Save**:
   - Changes are **instant** and saved to EEPROM
   - No need to reflash!

### Creating Layers

**Layers** let you have multiple layouts on one device (like Shift on a keyboard).

**Example: Gaming + Productivity Layers**

- **Layer 0**: MIDI notes (default)
- **Layer 1**: Gaming macros (WASD, abilities)
- **Layer 2**: Productivity (copy, paste, undo, etc.)

**To add a layer**:
1. In VIA, keys show "0" (Layer 0)
2. VIA allows dynamic layer creation
3. Assign a key to "MO(1)" (momentary Layer 1)
4. While holding that key, Layer 1 activates

### Macro Recording

VIA supports **macros** (key sequences):

1. Go to "Macros" tab in VIA
2. Click "+" to add
3. Type your sequence (e.g., `Ctrl+C {KC_DOWN} Ctrl+V`)
4. Assign macro to a key

---

## Use Cases

### 🎮 Gaming Setup

**Example: Fps Game Pad**

```
┌──────┬──────┬──────┬──────┐
│  Q   │  W   │  E   │  R   │  Abilities
├──────┼──────┼──────┼──────┤
│  A   │  S   │  D   │  F   │  Movement + Use
├──────┼──────┼──────┼──────┤
│ Ctrl │ Shift│ Space│ Tab  │  Crouch/Sprint/Jump/Map
├──────┼──────┼──────┼──────┤
│  1   │  2   │  3   │  4   │  Weapon Select
└──────┴──────┴──────┴──────┘
```

**Setup in VIA**:
- Remap each key to keyboard letters
- Enable NKRO (already enabled by default)
- Test in game

### 💼 Productivity Macros

**Example: Editing Shortcuts**

```
┌──────────┬──────────┬──────────┬──────────┐
│  Undo    │  Redo    │ Save     │ Save As  │
├──────────┼──────────┼──────────┼──────────┤
│  Cut     │  Copy    │ Paste    │ Find     │
├──────────┼──────────┼──────────┼──────────┤
│  Bold    │  Italic  │ Underline│ Link     │
├──────────┼──────────┼──────────┼──────────┤
│  Layer 0 │  Layer 1 │ Vol Down │ Vol Up   │
└──────────┴──────────┴──────────┴──────────┘
```

**Common Macros**:
- `Ctrl+Z` (Undo)
- `Ctrl+Shift+Z` (Redo)
- `Ctrl+S` (Save)
- `Ctrl+F` (Find)

### ♿ Accessibility Configuration

**One-Handed Layout Example**:

```
┌──────┬──────┬──────┬──────┐
│ Enter│ Space│ Bksp │ Esc  │  Common actions
├──────┼──────┼──────┼──────┤
│  Tab │  Up  │ Home │ End  │  Navigation
├──────┼──────┼──────┼──────┤
│ Left │ Down │ Right│ PgDn │  Arrow cluster
├──────┼──────┼──────┼──────┤
│ Copy │ Paste│ Undo │ Redo │  Edit actions
└──────┴──────┴──────┴──────┘
```

**Benefits**:
- All common functions on one hand
- Customizable to individual needs
- Mouse control available via VIA

### 🎵 MIDI Controller (Hybrid Mode)

Keep MIDI notes for music while adding shortcuts:

```
┌─────┬─────┬─────┬─────┐
│ C3  │ C#3 │ D3  │ D#3 │  Layer 0: MIDI Notes
├─────┼─────┼─────┼─────┤
│ G#2 │ A2  │ A#2 │ B2  │
├─────┼─────┼─────┼─────┤
│ E2  │ F2  │ F#2 │ G2  │
├─────┼─────┼─────┼─────┤
│ C2  │ C#2 │ D#2 │[L1] │  Hold [L1] for Layer 1
└─────┴─────┴─────┴─────┘

Hold [L1]:
┌──────┬──────┬──────┬──────┐
│ Play │ Stop │ Rec  │ Metro│  Layer 1: DAW Controls
├──────┼──────┼──────┼──────┤
│ Undo │ Redo │ Save │ Snap │
├──────┼──────┼──────┼──────┤
│ Mute │ Solo │ Arm  │ Mon  │
├──────┼──────┼──────┼──────┤
│ Vol- │ Vol+ │ Pan← │ ---- │
└──────┴──────┴──────┴──────┘
```

---

## Keyboard Shortcuts Reference

### QMK Special Keycodes

| Code | Function |
|---|---|
| `KC_TRNS` | Transparent (passes through to layer below) |
| `MO(n)` | Momentary layer n (hold to activate) |
| `TG(n)` | Toggle layer n on/off |
| `LT(n, kc)` | Tap for keycode, hold for layer n |
| `KC_MPLY` | Media play/pause |
| `KC_VOLU` | Volume up |
| `KC_VOLD` | Volume down |
| `KC_MUTE` | Mute |

### MIDI Note Codes

All QMK MIDI notes follow this pattern:
- `MI_C_2` = C in octave 2 (MIDI 36)
- `MI_Cs_2` = C# in octave 2 (MIDI 37)
- `MI_C_3` = C in octave 3 (MIDI 48)

Full reference: [QMK MIDI Keycodes](https://docs.qmk.fm/#/feature_midi)

### Mouse Control

| Code | Function |
|---|---|
| `KC_MS_U` | Mouse up |
| `KC_MS_D` | Mouse down |
| `KC_MS_L` | Mouse left |
| `KC_MS_R` | Mouse right |
| `KC_BTN1` | Mouse left click |
| `KC_BTN2` | Mouse right click |
| `KC_WH_U` | Scroll wheel up |
| `KC_WH_D` | Scroll wheel down |

---

## Troubleshooting

### Device Not Detected in VIA

**Problem**: VIA doesn't see your Dilla4x

**Solutions**:
1. **Check Firmware**: Ensure you flashed the **`via`** keymap, not `default`
2. **Browser**: Use Chrome or Edge (VIA requires Web HID)
3. **Permissions**: Allow browser to access USB devices
4. **Cable**: Try a different USB cable/port
5. **Manual Load**: See [VIA Setup Guide](../../firmware/qmk/dilla4x/keymaps/via/VIA_SETUP.md) for manual definition upload

### MIDI Not Working in DAW

**Problem**: DAW doesn't receive MIDI

**Solutions**:
1. **Check Keymap**: Ensure your active layer has MIDI keycodes (not regular keys)
2. **DAW Settings**: Select "Dilla4x Controller" as MIDI input device
3. **MIDI Channel**: Default is Channel 1 - verify in DAW
4. **USB Mode**: Some DAWs prefer dedicated MIDI firmware - consider Dilla4x-MIDI (v0.3.0)

### Keys Not Responding

**Problem**: Keys don't work or wrong keys trigger

**Solutions**:
1. **Reset EEPROM**: 
   - In VIA, use "Clear EEPROM" option
   - Or reflash firmware with QMK Toolbox
2. **Test in Text Editor**: Verify keys work outside specific software
3. **Check Layers**: You might be on wrong layer - press layer toggle key
4. **Physical Check**: Verify keyswitches are properly seated

### Firmware Too Large

**Problem**: "Firmware size exceeds flash" during compile

**Solutions**:
1. **Disable Features**: Edit `rules.mk`:
   ```makefile
   MOUSEKEY_ENABLE = no  # Disable mouse keys
   NKRO_ENABLE = no      # Disable NKRO
   ```
2. **Use Default Keymap**: Flash `default` instead of `via` (smaller)
3. **LTO Already Enabled**: The firmware already uses Link Time Optimization

### Can't Enter Bootloader

**Problem**: Device won't enter flashing mode

**Solutions**:
1. **Bootmagic**: Hold **top-left key** while plugging in USB
2. **Physical Reset**: 
   - Locate RST and GND pins on Pro Micro
   - Touch them together with tweezers/wire twice quickly
3. **Recovery Mode**: See [Recovery Guide](../../firmware/Dilla4x-MIDI/utils/recovery/README.md)

---

## Advanced Customization

### Building Your Own Keymap

1. **Fork the Repository**: https://github.com/Cypaloma/Dilla4x

2. **Create a Keymap**:
   ```bash
   cd ~/qmk_firmware/keyboards/dilla4x/keymaps
   cp -r via my_custom_keymap
   ```

3. **Edit `keymap.c`**:
   ```c
   const uint16_t PROGMEM keymaps[][MATRIX_ROWS][MATRIX_COLS] = {
       [0] = LAYOUT(
           KC_Q, KC_W, KC_E, KC_R,
           KC_A, KC_S, KC_D, KC_F,
           KC_Z, KC_X, KC_C, KC_V,
           KC_1, KC_2, KC_3, MO(1)
       ),
       [1] = LAYOUT(
           KC_ESC, KC_UP, KC_HOME, KC_END,
           KC_LEFT, KC_DOWN, KC_RGHT, KC_PGDN,
           KC_MUTE, KC_VOLD, KC_VOLU, KC_MPLY,
           KC_TRNS, KC_TRNS, KC_TRNS, KC_TRNS
       )
   };
   ```

4. **Compile and Flash**:
   ```bash
   qmk compile -kb dilla4x -km my_custom_keymap
   qmk flash -kb dilla4x -km my_custom_keymap
   ```

### Enabling Additional Features

Edit `~/qmk_firmware/keyboards/dilla4x/rules.mk`:

```makefile
# Add RGB underglow (if hardware supports)
RGBLIGHT_ENABLE = yes

# Add audio (if hardware supports)
AUDIO_ENABLE = yes

# Add tap dance
TAP_DANCE_ENABLE = yes
```

Then recompile.

### Using Community Layouts

Dilla4x is compatible with the `ortho_4x4` community layout:

```bash
# Use any ortho_4x4 keymap from community
qmk compile -kb dilla4x -km <community_keymap_name>
```

Browse community layouts: https://github.com/qmk/qmk_firmware/tree/master/layouts/community/ortho_4x4

---

## Additional Resources

- **QMK Documentation**: https://docs.qmk.fm/
- **VIA Configurator**: https://usevia.app/
- **QMK Discord**: https://discord.gg/qmk (community support)
- **Dilla4x Repository**: https://github.com/Cypaloma/Dilla4x
- **QMK Firmware Source**: [firmware/qmk/dilla4x](../../firmware/qmk/dilla4x/)

---

## Quick Start Checklist

- [ ] Flash the VIA keymap using QMK Toolbox or QMK CLI
- [ ] Verify device works (test keys in text editor)
- [ ] Open VIA configurator at https://usevia.app/
- [ ] Authorize device in browser
- [ ] Remap keys to your preference
- [ ] Test your layout
- [ ] Create additional layers as needed
- [ ] Save your configuration (automatic in VIA)

**You're now ready to use your Dilla4x as a fully programmable input device!**

---

*For MIDI-focused usage, see the [Dilla4x-MIDI Firmware Guide](How-to-Use-Dilla4x-MIDI.md).*

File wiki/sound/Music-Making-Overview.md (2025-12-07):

# Digital Music Making Overview

> [!NOTE]
> The Dilla4x with **Standard MIDI Firmware** works as a class-compliant MIDI controller. This guide assumes you are using that firmware.

## Connecting to Your Computer
(from "DAWs are terrifying" to "I want deep tools and open source everything")

## How to Choose
If big DAWs like Logic, FL, or Reason feel overwhelming:
1. Start with tools that limit options intentionally
2. Only add complexity when you hit limitations

This guide covers:
- Absolute beginners
- People needing low-clutter, accessible tools
- Advanced users wanting open source solutions

## Quick Navigation
1. [Easiest Options](Beginner-Guide.md) - Minimal setup
2. [Gentler DAWs](Intermediate-Guide.md) - Serious but approachable tools
3. [Advanced Paths](Advanced-Guide.md) - For technical users
4. [Open Source Toolkit](Open-Source-Tools.md) - Synths, drums & utilities

👉 Next: [Beginner's Guide](Beginner-Guide.md)

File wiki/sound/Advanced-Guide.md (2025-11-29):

# Advanced Music Production Paths

## Advanced DAW Setups
**Ardour + Carla**  
[https://ardour.org/](https://ardour.org/) + [https://kx.studio/Applications:Carla](https://kx.studio/Applications:Carla)  
- Professional DAW + modular plugin host  
- Route instruments/effects between applications  
- Supports LV2/VST/AU plugins  

**BespokeSynth**  
[https://www.bespokesynth.com/](https://www.bespokesynth.com/)  
- Modular patching environment  
- Visual rack-style interface  
- Scripting support for custom modules  

## Open Source Instruments
**Surge XT**  
[https://surge-synthesizer.github.io/](https://surge-synthesizer.github.io/)  
- Hybrid wavetable/subtractive synth  
- 1800+ presets, modular effects chain  

**Dexed**  
[https://asb2m10.github.io/dexed/](https://asb2m10.github.io/dexed/)  
- FM synth emulating Yamaha DX7  
- Patch librarian for hardware  

**Hydrogen**  
[https://hydrogen-music.org/](https://hydrogen-music.org/)  
- Advanced drum sequencing  
- Multi-layer sample support  

## Specialized Tools
**Carla**  
[https://kx.studio/Applications:Carla](https://kx.studio/Applications:Carla)  
- Plugin host for complex racks  
- Supports multiple plugin formats  

**Stochas**
[https://stochas.org/](https://stochas.org/)
- Probabilistic sequencer
- Polyrhythmic pattern generation

**Strudel**
[https://strudel.cc/](https://strudel.cc/)
- Web-based TidalCycles pattern engine
- Live coding with immediate feedback
- MIDI/OSC output support

## Example Configurations
1. **Modular Workstation**:
   BespokeSynth + Carla + Surge XT
2. **Pro Recording Setup**:
   Ardour + Hydrogen + Dexed
3. **Algorithmic Composition**:
   Sonic Pi/Strudel + Stochas + Helm

👉 Next: [Open Source Toolkit](Open-Source-Tools.md)

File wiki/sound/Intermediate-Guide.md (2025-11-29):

# Gentler DAWs for Serious Work

**LMMS**  
[https://lmms.io/](https://lmms.io/)  
- Open source FL Studio alternative  
- Pattern-based sequencing  
- Built-in instruments/effects  

**Ardour**  
[https://ardour.org/](https://ardour.org/)  
- Professional open source DAW  
- Audio + MIDI recording/mixing  
- Customizable workflow  

**Zrythm**  
[https://www.zrythm.org/](https://www.zrythm.org/)  
- Modern intuitive interface  
- Strong automation features  
- LV2 plugin support  

**BespokeSynth**
[https://www.bespokesynth.com/](https://www.bespokesynth.com/)
- Modular patching environment
- Visual rack-style interface
- Supports VST plugins

**Code-Based Tools**
- [Sonic Pi](https://sonic-pi.net/) - Live coding music environment
- [Strudel](https://strudel.cc/) - Web-based TidalCycles pattern engine

👉 Next: [Advanced Paths](Advanced-Guide.md)

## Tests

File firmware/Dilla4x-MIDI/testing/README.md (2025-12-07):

# Dilla4x Testing Infrastructure

Automated testing tools and test harnesses for firmware validation.

## Purpose

This directory contains tools for testing firmware logic, validating changes, and debugging issues in a controlled environment.

## Tools

### `firmware_test/`

Configurable test harness based on main firmware debounce/MIDI logic.

**Test Modes** (configure in source):
- `TEST_WATCHDOG`: Enable/disable watchdog timer
- `TEST_MIDIUSB`: Enable/disable MIDIUSB library (isolate pin conflicts)
- `TEST_VERBOSE`: Detailed trace logging vs minimal output

**Use cases**:
- Debugging debounce logic
- Testing if MIDIUSB causes pin read issues
- Validating firmware changes before deployment
- Reproducing production bugs in controlled environment

**See**: [firmware_test/README.md](firmware_test/README.md) for detailed usage

---

## Testing Strategy

### Current State

**Manual Testing**:
1. Hardware utilities ([`utils/`](../utils/)) validate physical connections
2. `firmware_test` validates firmware logic with serial tracing
3. Main firmware deployment tested manually on device

### Future Roadmap

See [ROADMAP.md](file:///home/morp/Documents/coding/projects/Dilla4x/ROADMAP.md) for planned testing infrastructure:

**Priority 2 - Testing**:
- Unit tests for debounce logic
- Integration tests for MIDI output validation
- Hardware-in-the-loop (HIL) test framework
- Automated test suite with CI/CD
- Regression test coverage

---

## Adding New Tests

When creating new test utilities:

1. **Create subdirectory**: `testing/your_test_name/`
2. **Add sketch**: `your_test_name.ino`
3. **Document**: Create `README.md` explaining:
   - What it tests
   - How to configure
   - Expected output
   - When to use
4. **Update this file**: Add entry to "Tools" section above

---

## Related

- **Hardware diagnostics**: See [`utils/README.md`](../utils/README.md)
- **Main firmware**: See [`FIRMWARE_SPEC.md`](../FIRMWARE_SPEC.md)
- **Future improvements**: See [ROADMAP.md](file:///home/morp/Documents/coding/projects/Dilla4x/ROADMAP.md)

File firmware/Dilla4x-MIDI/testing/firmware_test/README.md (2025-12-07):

# Firmware Test Harness

Configurable test utility for debugging main firmware with toggleable features.

## Purpose

Tests firmware debounce and MIDI logic in isolation with configurable modes to identify conflicts.

## Test Modes

Configure at top of `firmware_test.ino`:

```cpp
#define TEST_WATCHDOG 0    // 1=Enable watchdog, 0=Disable
#define TEST_MIDIUSB 0     // 1=Include MIDIUSB, 0=Exclude
#define TEST_VERBOSE 1     // 1=Detailed logging, 0=Minimal
```

### Mode Descriptions

**TEST_WATCHDOG**:
- Tests if watchdog timer interferes with pin reading
- Disable if you suspect watchdog causing resets

**TEST_MIDIUSB**:
- Tests if MIDIUSB library conflicts with digitalRead
- Disable to isolate USB/pin interaction issues

**TEST_VERBOSE**:
- Enable: Shows debounce state transitions and periodic status
- Disable: Only shows MIDI events

## Expected Output

### With TEST_VERBOSE=1
```
=== DILLA4X FIRMWARE TEST HARNESS ===
Configuration:
  Watchdog: DISABLED
  MIDIUSB: DISABLED
  Verbose: ENABLED
  Debounce: 30 ms

[DEBOUNCE] Key 0 -> PRESSED
[MIDI] Key 0 (Pin 2) -> NOTE ON
RAW: 0x1 STABLE: 0x1 LAST: 0x1
[DEBOUNCE] Key 0 -> RELEASED
[MIDI] Key 0 (Pin 2) -> NOTE OFF
```

### With TEST_VERBOSE=0
```
[MIDI] Key 3 (Pin 5) -> NOTE ON
[MIDI] Key 3 (Pin 5) -> NOTE OFF
```

## Common Test Scenarios

### Test 1: Isolate MIDIUSB Pin Conflict
```cpp
#define TEST_WATCHDOG 0
#define TEST_MIDIUSB 0    // Disable MIDIUSB
#define TEST_VERBOSE 1
```
**Goal**: See if buttons work without MIDIUSB library

### Test 2: Test Watchdog Impact
```cpp
#define TEST_WATCHDOG 1    // Enable watchdog
#define TEST_MIDIUSB 0
#define TEST_VERBOSE 1
```
**Goal**: See if watchdog causes resets during operation

### Test 3: Production-like Environment
```cpp
#define TEST_WATCHDOG 1
#define TEST_MIDIUSB 1
#define TEST_VERBOSE 0
```
**Goal**: Test configuration matching main firmware

## Usage

```bash
cd firmware/Dilla4x-MIDI/testing/firmware_test/

# Edit firmware_test.ino to set test flags

# Upload
arduino-cli upload -p /dev/ttyACM0 --fqbn arduino:avr:micro ./

# Monitor output
arduino-cli monitor -p /dev/ttyACM0
```

## Interpreting Results

| Output | Meaning | Action |
|---|---|---|
| `[DEBOUNCE]` messages | Keys stabilizing correctly | ✅ Debounce logic working |
| `[MIDI]` messages | MIDI events firing | ✅ State machine working |
| `RAW != STABLE` for long time | Debounce not settling | ❌ Check DEBOUNCE_MS value |
| No output on press | Pin not reading LOW | ❌ Check hardware with connection_scout |

## Relationship to Main Firmware

This test harness uses **EXACT COPY** of:
- `Config.h` constants
- `readPins()` function
- Debounce state machine logic
- MIDI trigger logic

**Differences**:
- Adds serial trace output
- Makes watchdog/MIDIUSB toggleable
- No actual MIDI output (just traces)

## Next Steps

After identifying issue:
1. Fix main firmware based on findings
2. Re-test with this harness
3. Deploy to device
4. Validate with [`connection_scout`](../../utils/connection_scout/)

---

[← Back to Testing](../README.md)

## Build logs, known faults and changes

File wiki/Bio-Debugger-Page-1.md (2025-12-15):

# BIO-DEBUGGER
Access-First Protocol for Technical Overwhelm • Educational (not medical advice) • Use what helps; skip what doesn't

## 1) STATE CHECK
- **GREEN (1):** I can think clearly. I'm learning.
- **YELLOW (2):** I'm strained; I can continue only if I simplify.
- **RED (3):** I'm flooded (panic/anger/shutdown/tears/urge to quit)

## 2) RED TRACK — 90-SECOND RESET
**A. STOP (20 sec)**  
Stop → Step back → Observe (body + urge) → Proceed with one deliberate action.

**B. EXHALE RESET (45 sec)**  
Inhale 2–3 sec → Exhale 6–8 sec × 5 rounds.

**C. ORIENT (30 sec)**  
Name 5 things you see → feel feet/hands → turn your head slowly and re-locate yourself in the room.

**If you're still RED after 2 rounds: STOP RULES (Block 5). Do not continue.**

## 3) YELLOW TRACK — REDUCE LOAD
- [ ] Close extra tabs/windows (leave only what you're using).
- [ ] Turn off notifications / mute chat for 10 minutes.
- [ ] Reduce sensory intensity (brightness/audio).
- [ ] Write the goal in one sentence: "I am trying to ____."
- [ ] Make the next step "tiny" (Block 4).
- [ ] Set a timer: 5 minutes (then reassess state).

## 4) NEXT TINY STEP
- [ ] Reproduce once (same steps, observe exactly what happens and collect info/errors).
- [ ] Single-variable change (research and change ONE thing → test once).
- [ ] Return to known-good (revert preset/file/version/settings).

## 5) STOP RULES
Stop and switch strategies if any are true:
- [ ] I've made 3 changes without understanding cause/effect.
- [ ] I'm repeating the same steps and learning nothing new.
- [ ] My body alarm is high (shaking, nausea, tunnel vision, shutdown).
- [ ] I'm arguing with myself / self-attacking / "I'm broken" thoughts.

Switch to (choose ONE):
- [ ] 5-minute break + water + return to Block 1
- [ ] Park it: write "next step" and stop for today

**Stopping is a skill. Pausing protects future progress.**

---

**Next:** [Page 2 - Tech Toolbelt](Bio-Debugger-Page-2.md)

Bio-Debugger v0.1 • 2025-12-15 • Page 1/3

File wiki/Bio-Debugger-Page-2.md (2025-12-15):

# BIO-DEBUGGER — PAGE 2/3
# TECH-TOOLBELT

**This page only works with Page 1.**  
Use Page 1 to check your state and take care of yourself first. Then use this toolbelt for technical steps.  
If you're RED or looping: return to Page 1 before doing more troubleshooting.

## TOOL 1 — ONE-CHANGE TROUBLESHOOTING
**Rule:** One change → one test → one conclusion.

1) **Pick ONE area (examples):**  
Physical (cable/port/power/device) • Computer (space/permissions/I-O selection) • App (one setting/toggle) • File/Data (different file/preset/smaller test) • Network/Service (only if relevant) • …etc.

2) **Pick ONE change:**  
Swap cable/port • restart one thing (app or device) • flip one setting • try a known-working file/preset/setup • simplify for one test (fewer devices/apps) • side-by-side compare (same steps, one difference)

3) **Call the result:**  
Better / Worse / Same / Unclear  
If Unclear → simplify the test (fewer steps, fewer moving parts) and try again with one change.

**Hard rule:** if you can't say what changed in one sentence, you changed too much.

## TOOL 2 — KNOWN-GOOD SNAPBACK
**Purpose:** get back to stable so you can move forward again.

Choose the smallest reset that fits where you are:
- Undo the last small change
- Switch to something you already know worked (file/preset/setup)
- Reset one setting to a neutral/default value (just for a test)
- If you're deep in the weeds: starting fresh (new project / clean setup) can be the fastest path back to clarity

Stop as soon as it works again.

## TOOL 3 — MICRO-RECORD (optional, minimal)
**Purpose:** keep notes tiny while preventing loops. Use only if it helps.

Record only:
- The small change (one sentence)
- The result/output (error text, or Better/Worse/Same/Unclear)

That's it.

---

**Previous:** [Page 1 - State Check](Bio-Debugger-Page-1.md) | **Next:** [Page 3 - Cognitive Traps](Bio-Debugger-Page-3.md)

Bio-Debugger v0.1 • 2025-12-15 • Page 2/3

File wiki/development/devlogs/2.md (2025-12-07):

Assembly is even slower than I had anticipated despite recognizing my estimates of workload were way off. 

Obvious, glaring problems to be solved in future attempts at the closed course structure we've attempted:
1. A research and development phase needs to be done PRIOR to the recruitment of the participants. 
2. dupont wires are not the move. Either expensive solid core duponts or wires with alligator clips, crimps, terminals, or other means of connecting the wires.
3. Realistically what this needed was a custom PCB that joined all of the grounds to common meant for keyswitches, to be a larger instrument that cound house a breadboard, or a purely DIY focused cousrse. 

Upon starting, this course was designed to have its participants build their own instruments from Arduinos, with their specifications customized per user. It was a closed course, with a set of instructions and a set of materials, and those materials proved problematic, as outlined in the previous log.

Administratively, this course took far longer than I had anticipated to begin, and as such, we had to pivot from the original idea and instead ship out prebuilt kits. THIS was where everything went wrong, in combination with the extra assembly steps our sub-par materials required.

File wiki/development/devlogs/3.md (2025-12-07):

Where to even begin. Controlsurface library didn't work on the arduino pro micro, and I had to write my own code for MIDIUSB and the midi functionality directly. This did save about 30-40% of the flash space, but it was a lot of work. Things are working much better now, as they work at all.

Then, the octaving was bad in multiple ways, the LEDS were tying up the musical function and usb communications of the device, so the midi flushing, led and usb functions, and priorities of all of them were rewritten. 

Then, we started finding all of the shorts we (I) had made the top half of the device, with the keyswitches having their positive shorted to ground and always being pulled low, making the key dead/always pressed. A script was written to detect all of the short. 

After that, it was made apparent something else was happening, and it turns out while the undersides of the boards looked fine, under the rubber spacers on the other side, the traces were shorted on the Arduino headers, so the bottom half of the device was shorted as well. We made another script to detect all of the shorts, and we found that many of the arduinos had been compromised in this way.

After WEEKS of troubleshooting, canabalizing devices and testing, we finally got eight out of twelve Dilla4x devices working. The remaining four were either shorting on one of the keyswitches in the top component, or their arduinos were shorting on the arduino headers. With the amount of time and resources we've put into this, it's clear that we needed to get these devices out with how long desoldering all of the headers and soldering new ones would take on top of fixing all of the keyswitches.

8/12 doesn't really feel like much of a victory, especially after the hundreds of hours, and it is frustrating that the problems that caused the broken devices were such amatuer mistakes. Bridges arduino headers and ground shorts. User error. Still... it's a victory of sorts.

After creating 13 Dilla4x devices, with the 5 not working only having minor issues preventing their being functional, I have gleaned the following info:

If left unwatched, the ground wire, if bare, will retain heat, sink through hot glue strain relief, and short positive to ground. You must be extremely careful until the ground wire is actually cooled. 

If using solid core, you must be careful when soldering the ground pins, as when the wire heats, it will sink through the plastic housing of the keyswitch, destroying the entire switch. 

If using dupont wires, you must ensure the hot glue strain relief has solid bond to the actual housing of the key and is fully cooled and fully encasing the solder joint, or it WILL snap off. 

If using a sketch that utilizes MIDIUSB natively, you likely will no longer be able to actually use the Arduino as a USB device, as the sketch will take over the USB functionality. This makes it so you can "soft brick" devices if you don't have a way to jump the reset pin.

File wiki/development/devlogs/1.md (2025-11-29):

11/19/25

Production of the closed course participant kits has begun in earnest. Before now, an estimated ~200 hours of work (not including communications) has gone into the project. The first thing I had to do was attack the scope creep of the initial idea, having been planning to offer a choice of two instruments, the Dill4x and KeybedO1R1.

The KBO1R1 was a piano layout style enclosure with parametric design that would allow for any layout of octaves and even organ-style rows of keys. O stands for octave, and R for row, with the numbers referencing the build configuration. Dilla4x was also planned to be parametric, going anywhere from 2x to 16x officially.

We have settled on using a hard base of the Dilla4x, a four by four MCP-style drum pad layout. 

There are a few notable problems we've run into before even starting:

One, we ordered dupont wires for solderless learning, but pins on keyboard switches and arcade buttons are flat, not square. They're incompatible with the duponts, meaning we have to solder all of them by hand. This wouldn't be such a bad thing, but the dupont wires are full of many tiny copper lines, not a solid core. While we pivoted to hand cutting and stripping every dupont to allow keyswitches to be experimented with solderless, The result is that the stripped dupont wires are either coated or just plain non-wetting for whatever reason, and the soldering difficulty is massive. Still, we're soldering hundreds of hand stripped wires to the pin. 

The second thing is that with this setup, while the wires can normally bend without breaking, when you tin the wires to the solder joint, it creates a hard crease where the dried solder stops and the soft wire returns, making the duponts snap off near immediately, often even without use. As such we also have to add strain relief to ever single keyswitch individually. 

Third, we've rewritten the firmware to revise analog potentiometers and faders, displays, rgbs, etc to be outside of the scope of the project, as well as the intelligent pin assigning matrix and user editable preset pre-sketch. Now, code is minimal, well commented, and easy to learn the actual function of.

Now, we actually begin, with last week and this week both being around sixty hour weeks of CAD modeling, course revision for the new pivoted plan, and kit assembly. CAD file is finally done thanks to OnShape granting me an educational license, as FreeCAD was unfortunately being a nightmare. The top and bottom of the instrument enclosure is done, and iteration is well underway, staring with the bottom half, or the tray that holds the arduino.

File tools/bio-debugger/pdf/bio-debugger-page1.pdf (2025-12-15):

# BIO-DEBUGGER

Access-First Protocol for Technical Overwhelm • Educational (not medical advice) • Use what helps; skip what doesn’t

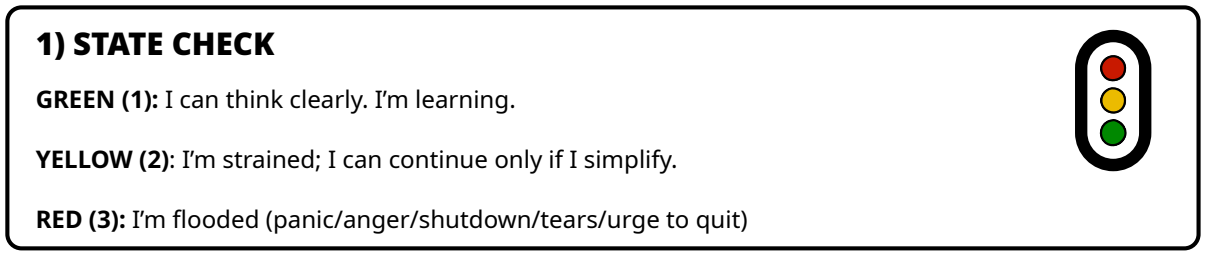
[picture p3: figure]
1) STATE CHECK

GREEN (1): I can think clearly. I’m learning.

YELLOW (2): I’m strained; I can continue only if I simplify.

RED (3): I’m flooded (panic/anger/shutdown/tears/urge to quit)

### 2) RED TRACK — 90-SECOND RESET

A. PAUSE (20 sec)
Pause → Step back → Observe (body + urge) → Prepare to proceed with a deliberate action.
B. EXHALE RESET (45 sec)
Inhale 2–3 sec → Exhale 6–8 sec × 5 rounds.
C. ORIENT (30 sec)
Name 5 things you see → feel feet/hands → turn your head slowly and re-locate yourself in the room.

If you’re still RED after 2 rounds: STOP RULES (Block 5). Do not continue.

### 3) YELLOW TRACK — REDUCE LOAD

☐ Close extra tabs/windows (leave only what you’re using).
☐ Turn off notifications / mute chat for 10 minutes.
☐ Reduce sensory intensity (brightness/audio).
☐ Write the goal in one sentence: “I am trying to ____.”
☐ Make the next step “tiny” (Block 4), maybe research one thing. ☐ Set a timer: 5 minutes (then reassess state).

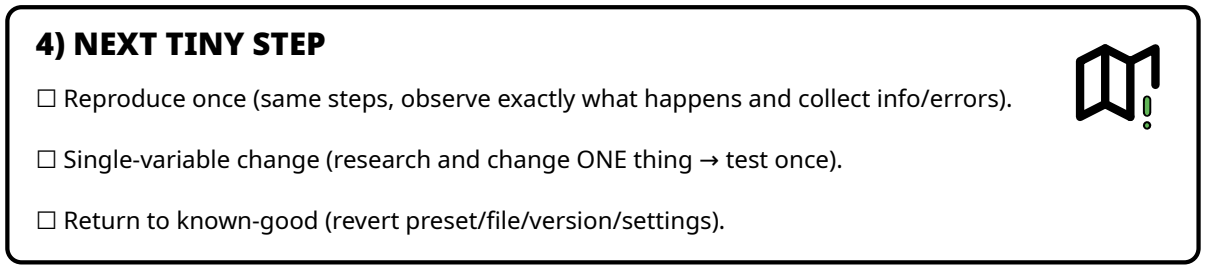
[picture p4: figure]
4) NEXT TINY STEP

☐ Reproduce once (same steps, observe exactly what happens and collect info/errors).

☐ Single-variable change (research and change ONE thing → test once).

☐ Return to known-good (revert preset/file/version/settings).

### 5) STOP RULES

Stop and switch strategies if any are true:
☐ I’ve made 3 changes without understanding cause/effect.
☐ I’m repeating the same steps and learning nothing new.
☐ My body alarm is high (shaking, nausea, tunnel vision, shutdown). ☐ I’m arguing with myself / self-attacking / “I’m broken” thoughts. Switch to (choose ONE):
☐ 5-minute break + water + return to Block 1
☐ Park it: write “next step” and stop for today
Stopping is a skill. Pausing protects future progress.

1

2

3

4

5

Bio-Debugger v0.1 • 2025-12-15• Page 1/3

Thank you: Tabler Icons (License: MIT)

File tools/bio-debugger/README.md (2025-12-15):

# Bio-Debugger

A mental health resource for non-shaming de-escalation techniques.

## What is Bio-Debugger?

The Bio-Debugger is a 3-page visual guide focused on de-escalation and self-regulation strategies. It provides practical tools for managing stress and maintaining mental well-being during development work or any challenging situation.

## Available Formats

The resource is available in multiple formats for accessibility:

- **PDF**: `pdf/bio-debugger-page1.pdf`, `page2.pdf`, `page3.pdf` - Printable format
- **PNG**: `png/bio-debugger-page1.png`, `page2.png`, `page3.png` - High-resolution images
- **SVG**: `svg/bio-debugger-page1.svg`, `page2.svg`, `page3.svg` - Vector graphics (scalable, editable)

## Usage

This resource is designed to be:
- Printed and posted in your workspace
- Kept as a digital reference
- Shared with team members or community

## Philosophy

The Dilla4x project includes this resource as part of our commitment to accessible, inclusive development. Mental health resources should be as available as technical documentation.

## License

Licensed under the Apache 2.0 License (same as parent project).

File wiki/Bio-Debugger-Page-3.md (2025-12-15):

# BIO-DEBUGGER — PAGE 3/3
# COGNITIVE TRAPS

Use when GREEN/YELLOW but thinking is blocking access to the Tech-Toolbelt.  
If RED or spiraling: Page 1.

**How to use:** Find the loop sentence → match a row → answer the question in one concrete sentence → then Page 2 (one test).  
**One-line rule:** Care first. Then one controlled test.

| # | Distortion (example loop sentence) | Counter-move question (answer once, then run one test) |
|---:|---|---|
| 1 | **ALL-OR-NOTHING** — "If it's not perfect, it's pointless." | What's the smallest useful outcome for this session? |
| 2 | **CATASTROPHIZING** — "This error means everything is broken." | What is the concrete impact right now (today), not the whole chain? |
| 3 | **OVERGENERALIZING** — "I'm awful with tech. I always mess this up." | Which exact step is failing, under what conditions? |
| 4 | **LABELING** — "I'm stupid / broken / useless." | Describe the situation without mentioning yourself: what is hard, and why? |
| 5 | **SHOULD STATEMENTS** — "I should already know this." | Drop "should." According to who? Who benefits from that rule? |
| 6 | **MIND READING** — "People will judge me / I'll look incompetent." | Assume you can't know. What action helps you either way? |
| 7 | **FORTUNE TELLING** — "This will never work." | What one small, reversible test would count as evidence either way? |
| 8 | **PERSONALIZATION** — "This broke because of me." | What changed last? What single test targets that change? |
| 9 | **MENTAL FILTER** — "Nothing works. Everything is failing." | What is one neutral fact you can verify right now? |
| 10 | **EMOTIONAL REASONING** — "I feel doomed, so it's doomed." | The feeling is real. What are the facts in one sentence? |

## IF THIS PAGE ISN'T HELPING
If you can't match a row, can't answer the question, or you're getting more activated:  
Go to Page 1 → YELLOW track or Stop Rules. If you stop, stop. When you return later: start again at Page 1.

---

**Previous:** [Page 2 - Tech Toolbelt](Bio-Debugger-Page-2.md) | **Start over:** [Page 1 - State Check](Bio-Debugger-Page-1.md)

Bio-Debugger v0.1 • 2025-12-15 • Page 3/3

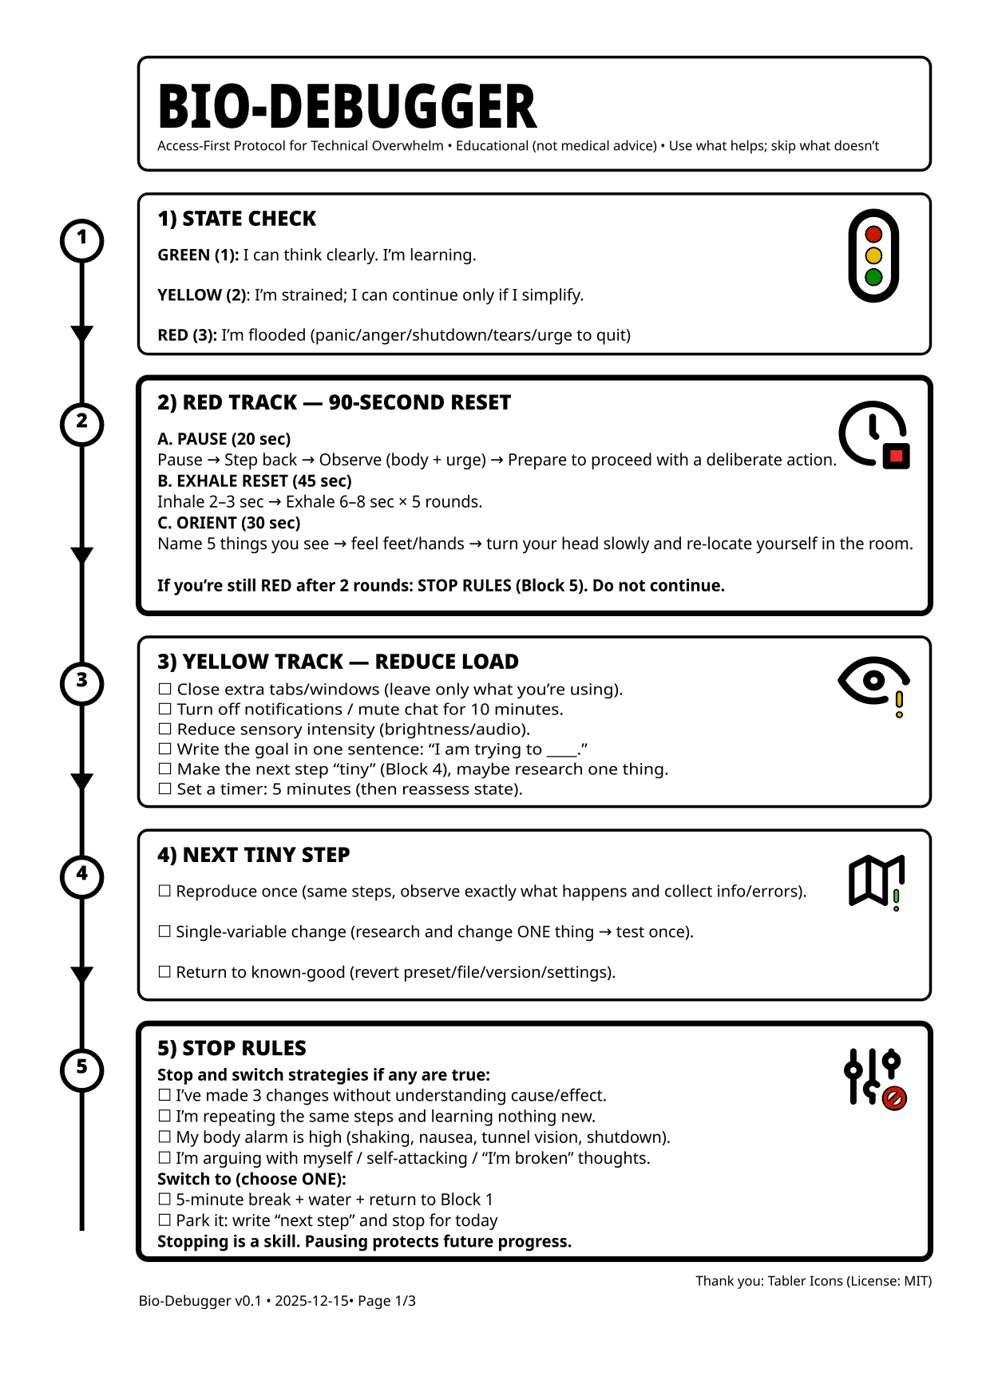
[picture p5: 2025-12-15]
tools/bio-debugger/png/bio-debugger-page1.png

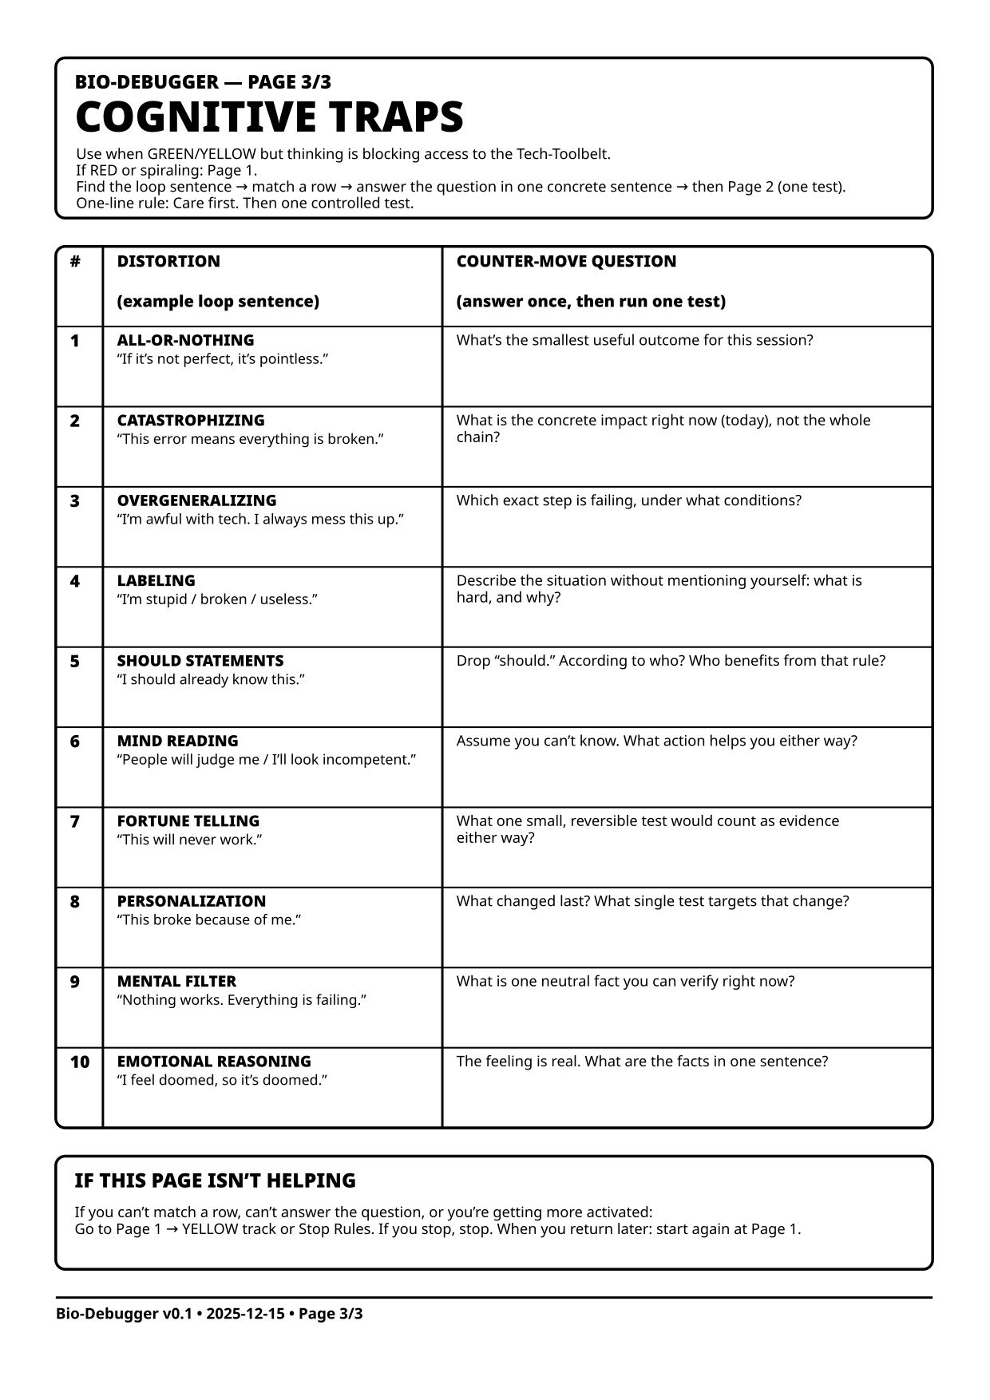
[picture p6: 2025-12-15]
tools/bio-debugger/png/bio-debugger-page3.png

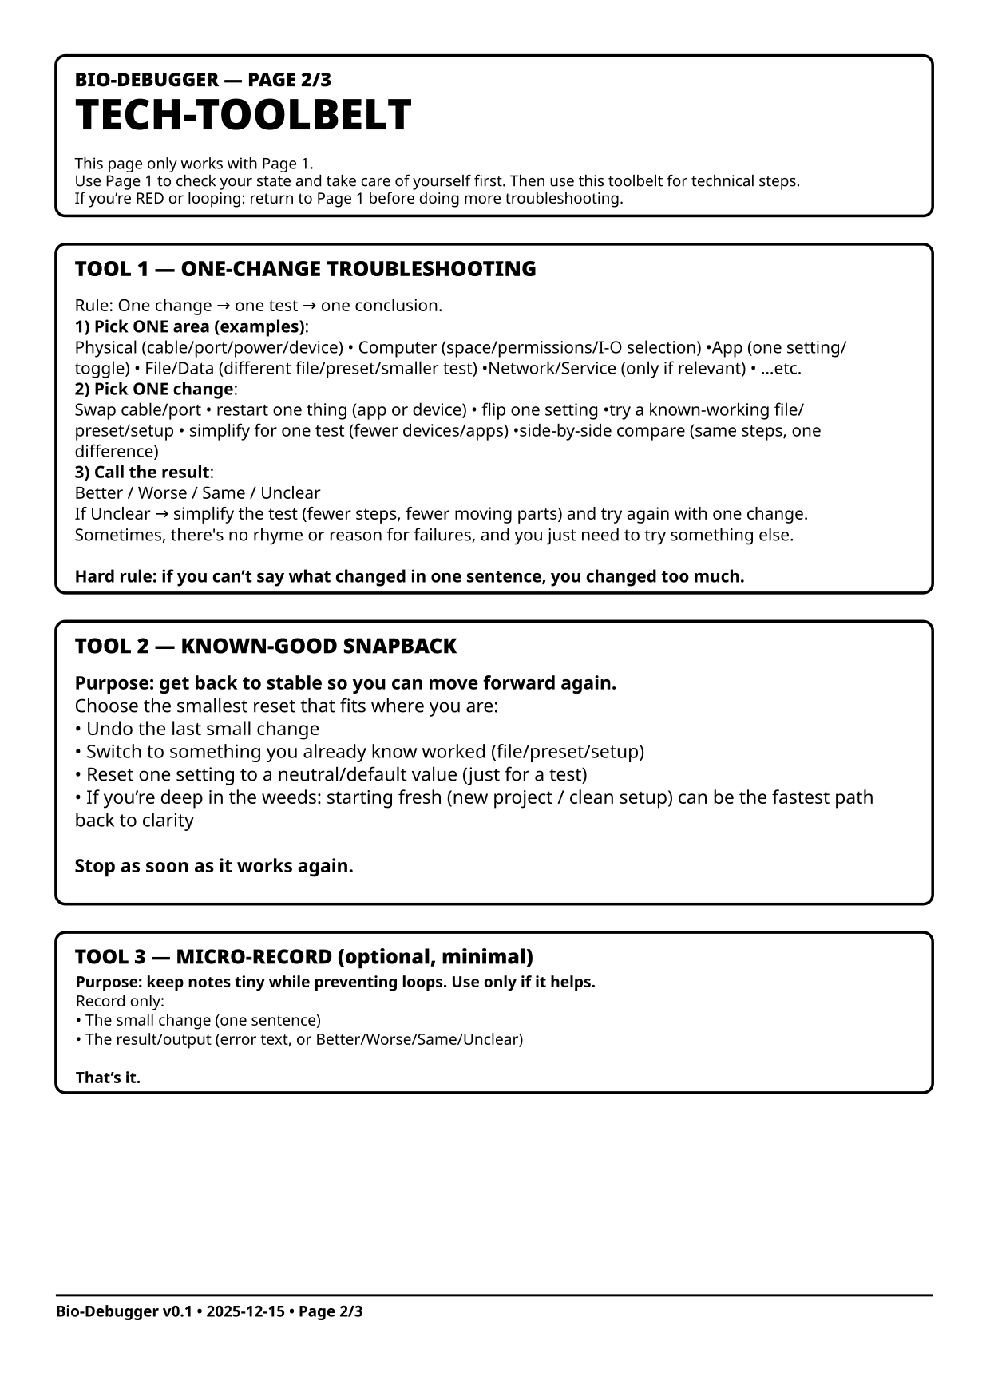
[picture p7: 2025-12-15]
tools/bio-debugger/png/bio-debugger-page2.png

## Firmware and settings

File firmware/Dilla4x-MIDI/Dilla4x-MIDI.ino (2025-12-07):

/*
 * Dilla4x Firmware - Zero Latency Implementation
 * Optimized for immediate response and simple feedback.
 */

#include <avr/wdt.h>
#include <MIDIUSB.h>
#include "Config.h"
#include "Utils.h"
#include "ChordManager.h"
#include "LedController.h"

// ========================================
// GLOBALS
// ========================================

// Button state tracking
uint16_t g_lastButtonState = 0;   // The state we last SENT to MIDI
uint16_t g_stableButtonState = 0; // The debounced physical state
unsigned long g_lastDebounceTime[NUM_KEYS] = {0};
constexpr int16_t NOTE_NONE = -1;
int16_t g_activeNotes[NUM_KEYS];

// Octave transposition
int8_t g_octaveOffset = 0; // -3 to +3 octaves

// Modules
ChordManager g_chordMgr;
LedController g_led;

// ========================================
// MIDI HELPERS
// ========================================

// Queue MIDI message (flushed at end of loop)
void sendNoteOn(uint8_t note, uint8_t velocity, uint8_t channel) {
  midiEventPacket_t noteOn = {0x09, uint8_t(0x90 | (channel & 0x0F)), note, velocity};
  MidiUSB.sendMIDI(noteOn);
}

void sendNoteOff(uint8_t note, uint8_t channel) {
  midiEventPacket_t noteOff = {0x08, uint8_t(0x80 | (channel & 0x0F)), note, 0};
  MidiUSB.sendMIDI(noteOff);
}

void sendAllNotesOff() {
  midiEventPacket_t cc = {0x0B, uint8_t(0xB0 | (MIDI_CHANNEL & 0x0F)), 0x7B, 0};
  MidiUSB.sendMIDI(cc);
}

// ========================================
// LOGIC
// ========================================

void handleButtonChange(uint8_t keyIndex, bool pressed) {
  // Calculate transposed note - clamp to valid MIDI range [0, 127]
  int16_t rawNote = BASE_NOTES[keyIndex] + (g_octaveOffset * SEMITONES_PER_OCTAVE);
  int8_t note = (rawNote < 0) ? 0 : (rawNote > 127 ? 127 : rawNote);
  
  if (pressed) {
    g_activeNotes[keyIndex] = note;
    sendNoteOn(note, 127, MIDI_CHANNEL);
  } else {
    int16_t storedNote = g_activeNotes[keyIndex];
    if (storedNote != NOTE_NONE) {
      sendNoteOff(static_cast<uint8_t>(storedNote), MIDI_CHANNEL);
      g_activeNotes[keyIndex] = NOTE_NONE;
    }
  }
}

void handleOctaveShift(const int8_t direction) {
  const int8_t newOctaveOffset = g_octaveOffset + direction;
  
  if (newOctaveOffset >= MIN_OCTAVE && newOctaveOffset <= MAX_OCTAVE) {
    // Octave takes precedence; shift immediately, then stop any held notes at original pitches
    g_octaveOffset = newOctaveOffset;
    uint16_t heldMask = g_stableButtonState;
    for (uint8_t i = 0; i < NUM_KEYS; i++) {
      if ((heldMask & (1U << i)) == 0) continue;
      int16_t storedNote = g_activeNotes[i];
      if (storedNote != NOTE_NONE) {
        sendNoteOff(static_cast<uint8_t>(storedNote), MIDI_CHANNEL);
        g_activeNotes[i] = NOTE_NONE;
      }
    }
    // Safety CC for hosts that rely on it
    sendAllNotesOff();
    MidiUSB.flush();
  }
}

// ========================================
// RECOVERY MODE (Unchanged)
// ========================================
// ... (Keeping the original recovery mode logic as it was robust)

static bool checkRecoveryMode() {
  for (uint8_t i = 0; i < RECOVERY_PINS_COUNT; i++) pinMode(RECOVERY_PINS[i], INPUT_PULLUP);
  for (uint8_t i = 0; i < RECOVERY_PINS_COUNT; i++) if (digitalRead(RECOVERY_PINS[i]) != LOW) return false;
  delay(RECOVERY_DEBOUNCE_MS);
  for (uint8_t i = 0; i < RECOVERY_PINS_COUNT; i++) if (digitalRead(RECOVERY_PINS[i]) != LOW) return false;
  return true;
}

void enterRecoveryMode() {
  Serial.begin(9600);
  TX_RX_LED_INIT;
  RXLED1;
  while (true) {
    TXLED0; delay(100);
    TXLED1; delay(100);
    if (Serial.available()) Serial.read();
  }
}

// ========================================
// MAIN
// ========================================

void setup() {
  wdt_disable();
  initPinMappings();
  for (uint8_t i = 0; i < NUM_KEYS; i++) pinMode(KEY_PINS[i], INPUT_PULLUP);
  for (uint8_t i = 0; i < NUM_KEYS; i++) g_activeNotes[i] = NOTE_NONE;
  
  g_led.init();
  Serial.begin(115200);

  if (checkRecoveryMode()) enterRecoveryMode();

  wdt_enable(WDTO_4S);
}

void loop() {
  wdt_reset();
  const unsigned long currentMillis = millis();
  
  // 1. Read Inputs
  const uint16_t rawPinMask = readPins();
  
  bool anyActivity = false;
  bool midiTraffic = false;

  // 2. Debounce & Process Keys
  for (uint8_t i = 0; i < NUM_KEYS; i++) {
    bool rawState = (rawPinMask & (1U << i)) != 0;
    
    // Check if state changed
    if (rawState != ((g_stableButtonState & (1U << i)) != 0)) {
       // Only process if stable for DEBOUNCE_MS
       if ((currentMillis - g_lastDebounceTime[i]) > DEBOUNCE_MS) {
         g_lastDebounceTime[i] = currentMillis;
         
         if (rawState) {
           g_stableButtonState |= (1U << i);
         } else {
           g_stableButtonState &= ~(1U << i);
         }
       }
    }
    
    // Fire MIDI immediately on state change confirmation
    bool confirmedState = (g_stableButtonState & (1U << i)) != 0;
    bool lastState = (g_lastButtonState & (1U << i)) != 0;
    
    if (confirmedState != lastState) {
      handleButtonChange(i, confirmedState);
      
      if (confirmedState) {
        g_lastButtonState |= (1U << i);
      } else {
        g_lastButtonState &= ~(1U << i);
      }
      midiTraffic = true;
    }
    
    if (confirmedState) anyActivity = true;
  }

  // 3. Absolute Priority: Flush MIDI Traffic BEFORE any other logic
  if (midiTraffic) {
    MidiUSB.flush();
  }

  // 4. Background Chord Check (Does not block MIDI)
  ChordEvent chord = g_chordMgr.update(currentMillis, g_stableButtonState);
  if (chord == ChordEvent::OCTAVE_UP) handleOctaveShift(1);
  if (chord == ChordEvent::OCTAVE_DOWN) handleOctaveShift(-1);

  // 5. Update LEDs (Activity on RX, Octave on TX)
  g_led.setActivity(anyActivity); 
  g_led.setShifted(g_octaveOffset != 0);
}

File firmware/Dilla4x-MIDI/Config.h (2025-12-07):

#ifndef DILLA4X_CONFIG_H
#define DILLA4X_CONFIG_H
#include <Arduino.h>
// #include <Control_Surface.h> // Removed for zero-latency raw implementation

// ========================================
// VERSION
// ========================================
constexpr uint8_t FIRMWARE_VERSION_MAJOR = 0;
constexpr uint8_t FIRMWARE_VERSION_MINOR = 3;
constexpr uint8_t FIRMWARE_VERSION_PATCH = 0;

// ========================================
// HARDWARE CONSTANTS
// ========================================
constexpr uint8_t NUM_KEYS = 16;
// Note: LED control now uses TXLED0/1 macros directly (see LedController.h)
// No LED_PIN or LED_ACTIVE_LOW constants needed

// Debounce time for keys (aggressive for low latency)
constexpr unsigned long DEBOUNCE_MS = 30;

// Chord hold time - how long to hold for octave shift
constexpr unsigned long OCTAVE_CHORD_HOLD_MS = 300;



// Recovery mode debounce delay
constexpr unsigned long RECOVERY_DEBOUNCE_MS = 50;

// ========================================
// LOGIC CONSTANTS
// ========================================
constexpr int8_t MIN_OCTAVE = -3;
constexpr int8_t MAX_OCTAVE = 3;
constexpr uint8_t SEMITONES_PER_OCTAVE = 12;
constexpr uint8_t MIDI_CHANNEL = 0; // MIDI channels are 0-indexed in MIDIUSB library

// MIDI note range (legacy constants from Control_Surface)
constexpr uint8_t MIN_MIDI_NOTE = 0;
constexpr uint8_t MAX_MIDI_NOTE = 127;

// ========================================
// PIN DEFINITIONS
// ========================================
constexpr uint8_t KEY_PINS[NUM_KEYS] = {
  2, 3, 4, 5,   // Row 0
  6, 7, 8, 9,   // Row 1
  10, 16, 14, 15, // Row 2
  A0, A1, A2, A3  // Row 3
};

// Recovery mode: Hold Key 0 and Key 15 at power-on to enter safe idle state
// for firmware upload if USB/MIDI stack fails.
// - Exposes CDC Serial (/dev/ttyACM*) making device flashable
// - TX LED blinks rapidly for visual confirmation (RX LED stays off)
// - Auto-detects Active-Low buttons (Active-High support available but commented)
constexpr uint8_t RECOVERY_PINS_COUNT = 2;
constexpr uint8_t RECOVERY_PINS[RECOVERY_PINS_COUNT] = {
  KEY_PINS[0],   // Top-Left
  KEY_PINS[15]   // Bottom-Right
};

// ========================================
// MIDI MAPPING
// ========================================
// Row 0: C3-D#3, Row 1: G#2-B2, Row 2: E2-G2, Row 3: C2-D#2
constexpr uint8_t BASE_NOTES[NUM_KEYS] = {
  48, 49, 50, 51,
  44, 45, 46, 47,
  40, 41, 42, 43,
  36, 37, 38, 39
};

// ========================================
// CHORD DEFINITIONS
// ========================================
// Left half (Cols 0,1): Keys 0,4,8,12 (col 0) and 1,5,9,13 (col 1)
constexpr uint16_t CHORD_MASK_DOWN = 
  (1U << 0) | (1U << 4) | (1U << 8) | (1U << 12) |  // Column 0
  (1U << 1) | (1U << 5) | (1U << 9) | (1U << 13);  // Column 1

// Right half (Cols 2,3): Keys 2,6,10,14 (col 2) and 3,7,11,15 (col 3)
constexpr uint16_t CHORD_MASK_UP = 
  (1U << 2) | (1U << 6) | (1U << 10) | (1U << 14) |  // Column 2
  (1U << 3) | (1U << 7) | (1U << 11) | (1U << 15);  // Column 3

// Chord threshold: all 8 keys on one side must be pressed
constexpr uint8_t CHORD_THRESHOLD = 6;
// Cancel threshold with margin: prevents accidental re-trigger during hand repositioning
constexpr uint8_t CHORD_CANCEL_THRESHOLD = 2;
constexpr uint8_t MIN_MEANINGFUL_KEYS = 1;

// ========================================
// VALIDATION & DERIVED CONSTANTS
// ========================================

// Pin validation for ATmega32U4 (pins 2-23, excluding serial pins 0-1)
static_assert(KEY_PINS[0] >= 2 && KEY_PINS[0] <= 23, "KEY_PINS[0] out of range");
static_assert(KEY_PINS[1] >= 2 && KEY_PINS[1] <= 23, "KEY_PINS[1] out of range");
static_assert(KEY_PINS[2] >= 2 && KEY_PINS[2] <= 23, "KEY_PINS[2] out of range");
static_assert(KEY_PINS[3] >= 2 && KEY_PINS[3] <= 23, "KEY_PINS[3] out of range");
static_assert(KEY_PINS[4] >= 2 && KEY_PINS[4] <= 23, "KEY_PINS[4] out of range");
static_assert(KEY_PINS[5] >= 2 && KEY_PINS[5] <= 23, "KEY_PINS[5] out of range");
static_assert(KEY_PINS[6] >= 2 && KEY_PINS[6] <= 23, "KEY_PINS[6] out of range");
static_assert(KEY_PINS[7] >= 2 && KEY_PINS[7] <= 23, "KEY_PINS[7] out of range");
static_assert(KEY_PINS[8] >= 2 && KEY_PINS[8] <= 23, "KEY_PINS[8] out of range");
static_assert(KEY_PINS[9] >= 2 && KEY_PINS[9] <= 23, "KEY_PINS[9] out of range");
static_assert(KEY_PINS[10] >= 2 && KEY_PINS[10] <= 23, "KEY_PINS[10] out of range");
static_assert(KEY_PINS[11] >= 2 && KEY_PINS[11] <= 23, "KEY_PINS[11] out of range");
static_assert(KEY_PINS[12] >= 2 && KEY_PINS[12] <= 23, "KEY_PINS[12] out of range");
static_assert(KEY_PINS[13] >= 2 && KEY_PINS[13] <= 23, "KEY_PINS[13] out of range");
static_assert(KEY_PINS[14] >= 2 && KEY_PINS[14] <= 23, "KEY_PINS[14] out of range");
static_assert(KEY_PINS[15] >= 2 && KEY_PINS[15] <= 23, "KEY_PINS[15] out of range");
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

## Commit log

2025-11-29 Add hardware parts directory for version control
    [Dilla4x v0.1 - Bottom v0.5.stl, Dilla4x v0.1 - Top v0.1.stl]
2025-11-30 Fix LED control and recovery mode for ATmega32U4
    [Config.h, Dilla4x-MIDI.ino, recovery.ino]
2025-12-07 docs: Update README and remove course materials
2025-12-15 Release: Dilla4x Platform v0.3.1 (QMK v0.1.1-alpha + Bio-Debugger)
    First major platform release featuring QMK firmware with VIA compatibility
    fixes, bio-debugger mental health resource, and build system improvements.
    ## QMK Firmware v0.1.1-alpha (UNTESTED ON HARDWARE)
    ### Critical Notice
    ⚠️ This firmware has NOT been tested on physical hardware as all devices
    have been sent to participants. Marking as ALPHA release. Use with caution.
    ### VIA Compatibility Fixes
    - Fixed via.json schema: corrected vendorId/productId format (0xfeed/0x4444)
    - Added proper menus structure for VIA V3 compatibility
    - Converted from diode matrix (COL2ROW) to direct pin configuration
    - Changed manufacturer fr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
